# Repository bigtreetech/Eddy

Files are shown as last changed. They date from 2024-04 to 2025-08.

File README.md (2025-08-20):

# Installation Guide For EDDY USB And Eddy Coil

> [!IMPORTANT]
> It is no longer necessary to use the BIGTREETECH fork when using the Eddy. You can now run mainline klipper. The guide that follows assumes that you are running mainline klipper. If you are migrating from the BIGTREETECH fork back to mainline then we suggest erasing all of the configuration and calibration data in your config file (including that within the auto save section) and performing the calibration again while using our latest configuration files.

# Index

- [BTT Eddy Dimensions and Probe Location](#btt-eddy-dimensions-and-probe-location)
- [Compiling Firmware](#compiling-firmware)
- [Printer Configuration](#printer-configuration)
- - [Selecting the right config file for your needs](#selecting-the-right-config-file-for-your-needs)
- - [Z Endstop](#z-endstop)
- [Drive Current Calibration](#2-drive-current-calibration)
- [Mapping Eddy Readings To Nozzle Heights](#3-mapping-eddy-readings-to-nozzle-heights)
- [Bed Mesh Calibration](#4-bed-mesh-calibration)
- [Temperature Compensation Calibration](#5-temperature-compensation-calibration-eddy-usb-only)
- [Extra Info](#extra-info)
- - [Bed Mesh Calibration Parameters](#bed-mesh-calibrate-parameters)
- - [Bed Mesh Scan Height](#bed-mesh-scan-height)
- - [Bed Mesh Rapid Scanning](#rapid-continuous-scanning)
- [FAQ - Frequently Asked Questions](#faq---frequently-asked-questions)
- - [Sometimes I get Error during homing probe: Eddy current sensor error](#sometimes-i-get-error-during-homing-probe-eddy-current-sensor-error)
- - [Sometimes I get a "Probe Triggered Before Movement" Error](#sometimes-i-get-a-probe-triggered-before-movement-error)
- - [Eddy is performing Z Hops when running Bed Mesh](#eddy-is-performing-z-hops-when-running-bed-mesh)
- - [Which Eddy version should I use?](#which-eddy-version-should-i-use)
- - [Error: gcode command < ANY GCODE COMMAND > already registered](#error-gcode-command--any-gcode-command--already-registered)
- - [My z-offset doesnt seem to save and resets, is there a work around or fix?](#my-z-offset-doesnt-seem-to-save-and-resets-is-there-a-work-around-or-fix)
- - [My Eddy Macros Conflict With My KNOMI Macros](#my-eddy-macros-conflict-with-my-knomi-macros)
- - [KAMP And Eddy](#kamp-and-eddy)

## Video Tutorial

For a video tutorial covering many of the points below, please watch the [video located here](https://drive.google.com/file/d/1uXiymZxoWhvRIwTwojOh0fGKmjitoytf/view?usp=sharing)

## BTT Eddy Dimensions and Probe Location

The Eddy has been designed to mount onto a standard Voron X carriage where the Omron inductive probe would usually mount. Additional mounts are provided for common printers [within the 3D folder of this repo.](https://github.com/bigtreetech/Eddy/tree/master/3D/EDDY_PRINT_PARTS) For detailed wiring and mounting instructions for both the Eddy and Eddy Coil, please refer to the PDF manual.

In all cases, mount the Eddy between 2mm and 3mm from the surface of the bed when the nozzle is just touching the bed. Mounting it too close could result in probe errors from the oscillator circuit signal saturating and mounting it too far could result in the oscillator circuit signal collapsing. Use thin shims (such as business cards) to measure this distance approximately.

> [!IMPORTANT]
> When mounting the Eddy, always ensure that the rear (where the electronic components are located) is situated further away from the hotend than the front.

> [!TIP]
> When installing the Eddy (USB version), try to avoid running the cable alongside other cables that are very electrically noisy such as stepper motor cables. If you must run it alongside such cables then do your best to separate the two. If there is slack remaining in the cable, do not wind it in a coil, rather wind it in a figure of 8.

> [!IMPORTANT]
> Some people confuse the current calibration height of 20mm with the mounting height of 2-3mm. The 20mm height is only used when calibrating the coil current later in this guide.

The dimensions below will help you to understand where the center of the coil is when measuring the X and Y offsets from point 15.

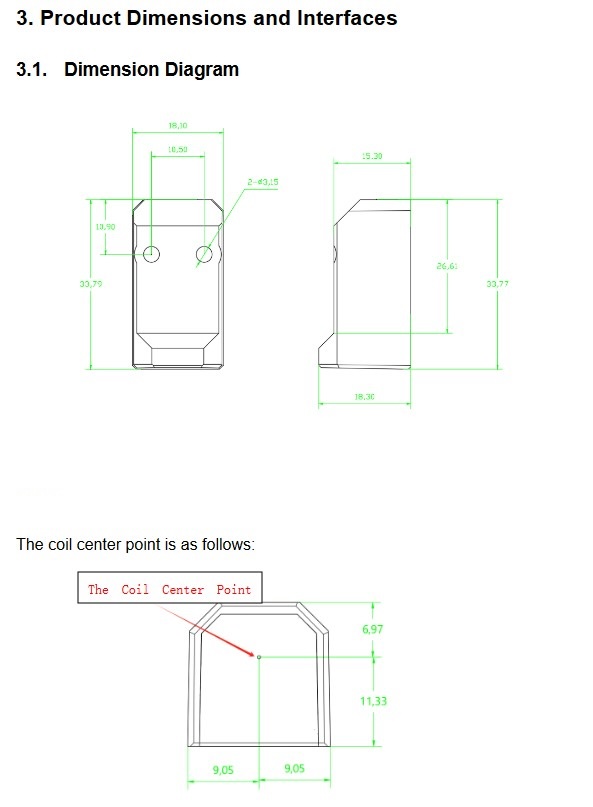
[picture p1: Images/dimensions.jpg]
Dimensions


## Compiling Firmware

> [!IMPORTANT]
> Eddy and Eddy Coil are ONLY compatible with klipper installations that are using a virtual environment based on python 3. Even if you have python 3 installed on your system this does not mean that your klippy virtual environment has been created using python 3. If you receive an error that says something like: `Internal error during connect: split() takes no keyword arguments` then you have a klippy host that is based on a python 2 virtual environment and you need to get it upgraded. The easiest way to do this is to use [KIAUH](https://github.com/dw-0/kiauh) which will allow you to reinstall the klippy host without overwriting your configs while selecting the python 3 option.

> [!IMPORTANT]
> The firmware compilation instructions below only apply to the Eddy USB. If you are using an Eddy Coil then you will have it connected to the I2C port on a toolboard. You will need to compile firmware for that toolboard using the master klipper branch and then install it onto that toolboard. When configuring the Eddy within Klipper you will just need to specify that it communicates using the I2C port on that toolboard which will depend on the pins for that board.
>
> If you are coming from the old BIGTREETECH branch of klipper then we recommend using KIAUH to move back to the mainline branch. We also recommend updating the firmware on all of your klipper devices so that it too is running on a binary compiled from mainline.

1. Ensure that you are using mainline klipper by typing the following commands via SSH:

```
cd ~/klipper
git checkout master
```

> 2. Next, type

```
cd ~/klipper
make menuconfig
```

3. Use these settings to compile the firmware.

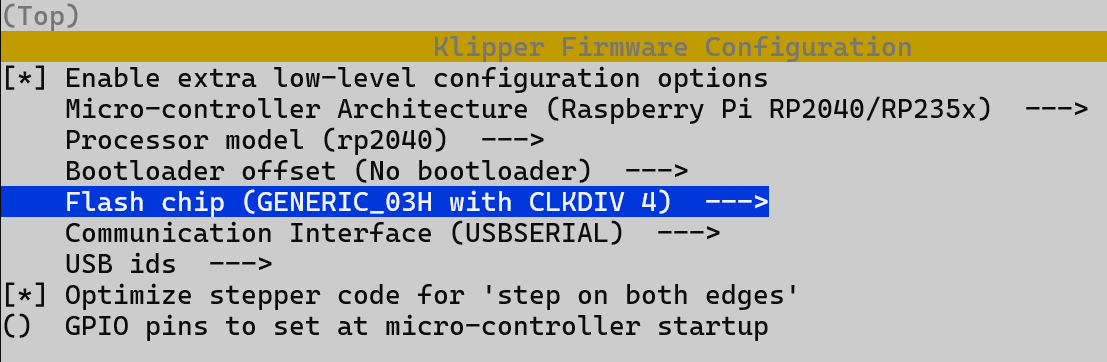
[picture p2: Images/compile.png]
Firmware Image
   

> [!WARNING]
> If you do not change the Flash chip configuration to the CLKDIV 4 one pictured, your probe will appear to work normally at first, however it will only intermittently start up when powered on. 

5. Once set, hit 'Q' and when asked, select yes to save.
6. Type `make` to compile.
7. Disconnect power to Eddy
8. Push and hold boot button on Eddy (Its next to where the cable plugs in) and at the same time, plug in the cable to your BIGTREETECH Pi.

> [!IMPORTANT]
> Don't disassemble your Eddy. The button is fully accessible without disassembly. The image is shown in an exploded view to make the button easier to see.

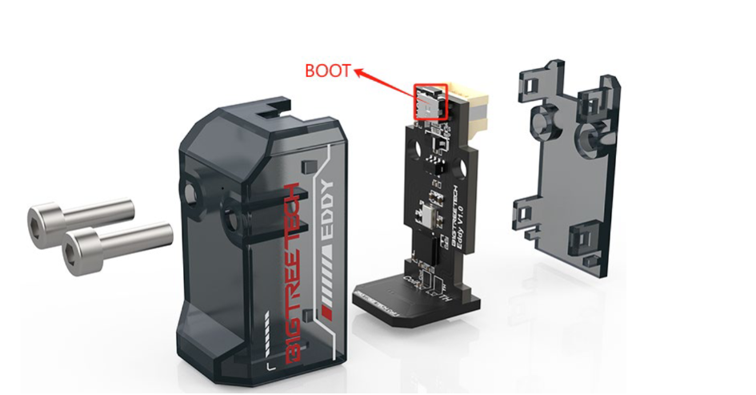
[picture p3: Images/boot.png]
Boot Image


8. SSH into host device
9. Type `lsusb` into the command line. You should see eddy.

LSUSB Image

10. Type `cd ~/klipper` into command line
11. Type `make flash FLASH_DEVICE=2e8a:0003`
    Remember to change 2e8a:0003 to your device ID you found in step 9
12. Type `ls /dev/serial/by-id/*` into the command line. The found device will be what you enter into your klipper config under [mcu eddy] for the Serial variable.

13. Type into command line `sudo reboot`

## Printer Configuration

> [!IMPORTANT]
> Read these steps well. Following them closely will help to ensure that your installation works without any hassles.

### Select the right config file for your needs

14. Now that you have the right firmware loaded onto your device, it is time to complete the Klipper configuration. BIGTREETECH provides three different sample configuration files to get you going. You will need to decide which one suits your needs the best. Choose the file that works best for you based on the criteria below. Read the comments in the selected configuration file carefully as they will help you to understand how to modify certain parameters to your installation.

- You wish to use the Eddy as a probe but will use another device as the z-endstop - [Use this config with no homing](sample-bigtreetech-eddy.cfg)
- You wish to use the Eddy as a probe AND as the z-endstop - [Use this config which includes homing](sample-bigtreetech-eddy-homing.cfg)
- You wish to use the Eddy as a probe AND as the z-endstop and would like to use the beta z-offset functionality - [Use this config which includes homing and z-offset](sample-bigtreetech-eddy-zoffbeta.cfg)

Whichever config you select, copy the entire contents into your printer.cfg file.

### Z Endstop

As mentioned in the paragraph above, you can use the Eddy as the z endstop or you can use another device as an endstop. If you decide to use another device as an endstop then set up your homing and endstop according to that device.

15. If you want to enable Z-Homing/Endstop for the eddy do the following things:

a. Under your [stepper_z] in printer.cfg change `endstop_pin: PA5` to `endstop_pin: probe:z_virtual_endstop` and comment out or remove `position_endstop: 0`. Note that your current endstop may not be PA5 so just look for the line that matches your current endstop and change it.

b. Ensure that you have selected the correct sample configuration file and that the entire contents of that file have been copied into your `printer.cfg file`. Take note that if you are using a KNOMI then there may be some macros that conflict with the macros in the KNOMI.cfg file. To resolve the conflicts, comment out the macros in the KNOMI.cfg file and uncomment the lines from the Eddy macros that deal with KNOMI functionality.

c. Edit the parts of the config file that are unique to your setup. These may be things like those in the list below. Follow the comments in the config file to help you to edit the values so that they work best with your setup.

- MCU serial
- X offset and Y offset
- Mesh_min and mesh_max
- Home_xy_position

> [!IMPORTANT]
> The sample configuration requires you to adjust the **x_offset** and **y_offset** to match your probe position relative to your nozzle. You can do that by following these steps found [HERE](https://www.klipper3d.org/Probe_Calibrate.html) and also by using the images at the top of this guide which show the center location of the Eddy coil. The settings for the standard Voron X carriage mount are included in all sample configuration files.

## 2. Drive Current Calibration

With the firmware and configuration done, you are now ready to begin the probe calibration.

16. Place Eddy Approx. 20mm above the bed. If you plan to use the Eddy as an endstop then you will not yet be able to home with it and you will need to manually move the gantry or bed such that the Eddy is 20mm above the bed.
17. From Mainsail or Fluidd run the command `LDC_CALIBRATE_DRIVE_CURRENT CHIP=btt_eddy`
18. Type `SAVE_CONFIG` to save the drive current to your config

## 3. Mapping Eddy Readings To Nozzle Heights

Now that the drive current has been calibrated, the Eddy will be able to obtain readings from the print bed. Klipper needs to know how those readings correspond to the height of the nozzle. The following calibration procedure positions the nozzle on the bed so that the z height is = 0. It then takes readings from the Eddy as it gradually increases the nozzle height so that it can map those readings to known heights. Follow the steps below to perform this essential calibration.

> [!TIP]
> If you ever find that the nozzle is sitting either too high or too low when it is supposed to be at z=0 then performing this quick calibration again will likely solve your issue. There is no need to set a z-offset. Movement of the probe relative to the nozzle through maintenance may result in the need for this calibration.

> [!TIP]
> Choose your own adventure!
> If you want to run the mapping the manual way then follow steps 22 thru 26
> If you want the easy way then simply follow steps 19 thru 21

19. Send the command `PROBE_EDDY_CURRENT_CALIBRATE_AUTO CHIP=btt_eddy`
20. Follow the prompts on the klipper UI to lower the nozzle until it sandwiches a piece of paper between it and the bed but be careful not to dig into the bed. The paper should still be able to move with some force applied.
21. Click accept and watch as the Eddy performs the mapping. Be sure to send `SAVE_CONFIG` when it is done. Skip ahead to [Bed Mesh Calibration](#4-bed-mesh-calibrationbed-mesh-calibration).

> [!TIP]
> Only perform the steps below if you did not perform steps 19 thru 21.

22. Home X and Y axes with command `G28 X Y`
23. Make sure you dont have a bed heightmap loaded. Send `BED_MESH_CLEAR` from the console to clear the heightmap.
24. Move Nozzle to Centre of the bed with `G0 X125 Y125 F6000` . The given command assumes a 250x250 printer but you will need to adjust it for your bed size. Take your bed size and divide it by 2 on X and Y and then use those values for the X and Y values in the command.
25. Start the mapping by typing `PROBE_EDDY_CURRENT_CALIBRATE CHIP=btt_eddy`. You will see an adjustment box that will allow you to lower the nozzle. Lower the nozzle until it sandwiches a piece of paper between it and the bed but be careful not to dig into the bed. The paper should still be able to move with some force applied.

26. Once completed use `SAVE_CONFIG`

## 4. Bed Mesh Calibration

> [!IMPORTANT]
> Before you do this, it's a good idea to perform a Quad Gantry Leveling (Voron etc)

27. Home All Axes
28. Use command `BED_MESH_CALIBRATE METHOD=rapid_scan`
29. Once completed use `SAVE_CONFIG`

## 5. Temperature Compensation Calibration (Eddy USB ONLY)

> [!TIP]
> The following steps (30-38) are for Eddy USB Only. Eddy Coil doesnt have temperature compensation so these steps should be disregarded.

30. Home All Axes and move Z 5 mm above the bed by typing `G0 Z5` or using the movement UI.
31. Set idle timeout by typing `SET_IDLE_TIMEOUT TIMEOUT=36000`
32. Run `TEMPERATURE_PROBE_CALIBRATE PROBE=btt_eddy TARGET=56 STEP=4`
33. This will cause the UI to display the z axis adjustment box. Use [the paper method](https://www.klipper3d.org/Bed_Level.html#the-paper-test) mentioned here to pinch a sheet of paper between the nozzle and the bed and then accept the value.
34. Turn on your heat bed to the maximum value and your nozzle to 220C.
35. If you are in a room with an air-conditioner or an open window, it would be good to turn it off and/or close the window. We want the temperature of the Eddy to rise and breezes will stop that.
36. As the Eddy temp rises you will automatically be asked to perform the paper pinch method at each 4C interval. Be careful not to burn yourself on the bed as the bed can get quite hot.
37. Repeat the paper test method until the calibration completes. If you find that the temperature of the Eddy is no longer increasing then you can end the calibration early using the relevant command below.

> [!NOTE]
> By default the calibration procedure will request a manual probe every 4C between samples until the TARGET is reached.
>
> The following additional gcode commands are available during drift calibration.
>
> `TEMPERATURE_PROBE_NEXT` may be used to force a new sample before the step delta has been reached.
>
> `TEMPERATURE_PROBE_COMPLETE` may be used to complete calibration before the TARGET has been reached.
>
> `ABORT` may be used to end calibration and discard results.

> [!TIP]
> The Eddy thermal calibration process not only accounts for Eddy probe drift but it also accounts for thermal expansion of the mechanical components within your machine. This expansion can be very significant and it can result in poor first layers when using other probes. It is important to keep in mind that if you perform the thermal calibration with the nozzle and the heated bed turned on then there will be thermal expansion from both the hotend and the heated bed. Therefore, if you later try to perform a paper test and only have either the nozzle or the heated bed turned on you may find that there is about a 0.05 gap (not enough to cause a first layer issue but enough to feel less of a pinch on the paper). If this all sounds a bit confusing then don't worry. All you need to know is that you should perform the calibration with the bed and the nozzle both hot and then subsequently print with the bed and the nozzle both hot and you will get fantastic first layers.

38. Youre all done and your Eddy will now give you a beautiful first layer across a wide temperature range! :)

# Extra Info

## Z-Offset

> [!TIP]
> This section only applies to those who are using the Eddy for homing.

The Eddy should not need the use of a z-offset since it is calibrated to understand where `z=0` is. Nevertheless, if you would like to use a z-offset then you should use the [sample config file that includes z-offset functionality.](sample-bigtreetech-eddy-zoffbeta.cfg)

To determine the correct Z-offset, follow the steps below.

- Home your printer.
- Place a piece of paper beneath the nozzle.
- Use mainsail or fluidd to set the z height to `z=0`. DO NOT babystep to get the nozzle to `z=0`! Set it as the z-axis height.
- After setting the z-axis height to `z=0` check if the pinch on your paper is just right. If not, then use babystepping to go up or down.
- After babystepping to the correct height, save the adjustment using the button on the mainsail or fluidd UI.

## Bed Mesh Calibrate Parameters

The Eddy allows you to perform a very rapid bed mesh scan before each print to ensure that you get the best first layer possible. To do this, we recommend replacing the standard BED_MESH_CALIBRATE macro with our modified version from the sample configuration file and then including a BED_MESH_CALIBRATE call in your print start macro.

To find out more about the parameters used in the bed mesh scan you can read the Klipper documentation here: [Bed Mesh Calibration](https://www.klipper3d.org/G-Codes.html#bed_mesh_calibrate)

## Bed Mesh Scan Height

The scan height is set by the `horizontal_move_z` option in `[bed_mesh]`. In
addition it can be supplied with the `BED_MESH_CALIBRATE` gcode command via the
`HORIZONTAL_MOVE_Z` parameter.

The scan height must be sufficiently low to avoid scanning errors. Typically
a height of 2mm (ie: `HORIZONTAL_MOVE_Z=2`) should work well, presuming that the
probe is mounted correctly.

It should be noted that if the probe is more than 4mm above the surface then the
results will be invalid. Thus, scanning is not possible on beds with severe
surface deviation or beds with extreme tilt that hasn't been corrected.

## Rapid (Continuous) Scanning

When performing a rapid bed mesh scan there is little time to accumulate many samples per point so that they can be averaged and have noise removed. Therefore a rapid scan may not be as accurate as a standard bed mesh scan but in most cases it will still produce a fine first layer.

Rapid scans can be improved by allowing the travel planner to slightly overshoot the scanned bed mesh and smooth the moves. You can configure this overshoot in the bed_mesh configuration section using the `scan_overshoot: ` parameter. Note that you will need to ensure that the axis can travel to the mesh boundary plus this overshoot value on your printer so be careful not to specify a value that is too high. Usually 8mm is plenty.

# FAQ - Frequently Asked Questions

## Sometimes I get `Error during homing probe: Eddy current sensor error`

- This generally indicates that the oscillator within the Eddy sensor is not at a valid value before the probe/homing attempt starts. We recommend trying the following steps:

1. Double check your probe height. It may be that it is too close to the bed or too high. Remember that we recommend that it is at 2mm-3mm above the bed when the nozzle is just touching the bed. Around 2.5mm is optimal in most cases but if you are finding that your probe is having errors at high temperatures then try to drop it just below 2mm. However, if your probe is having errors during QGL attempts then you may need to raise it slightly.
2. After you have adjusted the probe height, remove all of the calibration settings from your config file and recalibrate the eddy.
3. If you still receive this error then increase the `reg_drive_current` value to 16 from 15 if it is currently set to 15.

## Sometimes I get a "Probe Triggered Before Movement" Error

- This will happen when you try to execute two successive `PROBE` commands. Always raise the gantry by a few mm between `PROBE` commands to avoid this.

## Eddy is performing Z Hops or pausing when running Bed Mesh

- Make sure you are using the correct macro call.
  `BED_MESH_CALIBRATE METHOD=rapid_scan`
- Remove or alter KAMP - Adaptive Bed Mesh and any custom BED_MESH_CALIBRATE macros. Use klipper adaptive mesh instead or alternatively do not include KAMP/Adaptive_Meshing.cfg in your KAMP_Settings.cfg
  [Information on Adaptive Mesh Here](https://www.klipper3d.org/Bed_Mesh.html#adaptive-meshes)

## Which Eddy version should I use?

- It depends on your needs. Eddy USB and Eddy Coil are nearly identical, however Eddy Coil is more for toolhead boards and connects via I2C connectors.
- Eddy Coil does not have temperature compensation and so it may be less reliable for homing if you are using it within a sealed chamber..

## Error: gcode command < ANY GCODE COMMAND > already registered

- This will happen when you have conflicting gcode macros. Check all of your gcode macros for ones that share the same name and arbitrate the conflicts. Generally, you should select the functionality from the Eddy macros if there is a conflict and you are not sure what to do.

## My z-offset doesnt seem to save and resets, is there a work around or fix?

- Coming from a standard probe, this may seem like a bug. However if you have calibrated the Eddy correctly and are using the special homing macros, then there will be no need for a z-offset. Explaining why is a bit long winded but essentially when it comes to an Eddy, the z-offset parameter does not adjust the height at which the nozzle prints, it just adjusts the height at which homing or probing triggers. If you have a mind that enjoys understanding things at a deeper level then here is a writeup to give you something to chew on: [Z-Offsets with Eddy Current Probes](https://gist.github.com/bigtreetech/484380b26be613b9139bc537510393df)
- While we strongly recommend simply performing the Eddy probe calibration in order to get a nozzle height that is just right, you can still simulate a standard z-offset by using the [Z-offset beta sample configuration file](sample-bigtreetech-eddy-zoffbeta.cfg). Simply uncomment any macro that is related to the beta z-offset functionality and you will be able to use the standard mainsail buttons to raise/lower then nozzle and save that height as a z-offset.

## My Eddy Macros Conflict With My KNOMI Macros

- The Eddy and the KNOMI share similar Macros. All of the needed functionality for the KNOMI has been built into the Eddy macros. Please comment out the KNOMI macros which conflict and use the Eddy macros.
- Note that you may need to uncomment some lines in the Eddy macros that are specifically included for people who run the KNOMI. Check the macros to see which lines have been commented and then uncomment them if they are needed for KNOMI.

## KAMP And Eddy

> [!WARNING]  
> [KAMP aka Klipper-Adaptive-Meshing-Purging](https://github.com/kyleisah/Klipper-Adaptive-Meshing-Purging) should be removed from your klipper prior to using Eddy. Please comment out the include line. ie `#[include ./KAMP/adaptive_meshing.cfg]` from your KAMP_SETTINGS.cfg
>
> Instead KAMP has been integrated into klipper as of January 2024 and you should use the ADAPTIVE=1 option in your BED_MESH_CALIBRATION calls. You can find more [Information on Adaptive Mesh Here](https://www.klipper3d.org/Bed_Mesh.html#adaptive-meshes)

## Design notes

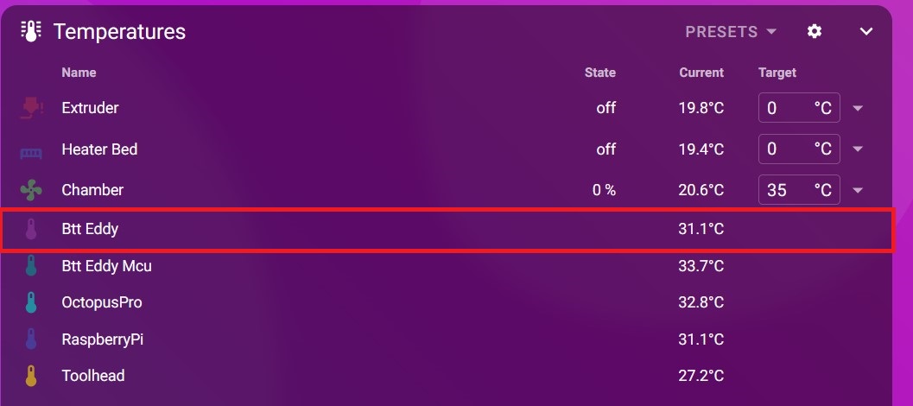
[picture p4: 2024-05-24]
Images/eddy-temp.jpg

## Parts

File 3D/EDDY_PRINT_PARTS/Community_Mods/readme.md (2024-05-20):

* The `Community_Mods` file is for 3D printing community users to share and contribute models. We are very grateful for their sharing and contribution. However, these files have not been verified by BIGTREETECH and may have compatibility issues. If you encounter compatibility issues as a result, please let us know by initiating an [issues](https://github.com/bigtreetech/Eddy/issues)

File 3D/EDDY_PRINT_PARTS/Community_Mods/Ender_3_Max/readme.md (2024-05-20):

Adjustable mount for BTT Eddy probe v1 ( USB probe version ) to fit Creality Ender 3 Max carriage plate

Designed by @DaveTheBuskerUK - 20240510

There are 2 parts to the actual mount -

The slide has holes in it for the supplied M3 bolts that come with the Eddy probe, I use the shorter 2, the holes are sized to self tap when you screw in the m3 bolts, if they pull out you could use the longer bolts with nylock nuts on the back of the slide. At the top of the slide is a pair of larger holes for a cable tie to retain the probe cable. Then the long slotted hole is for 2 M3x10mm bolts which go through the slide, through the spacer and fit into the threaded holes in the E3 Max carriage plate, these allow for vertical adjustment of the probe.

The spacer fits between the slide and the carriage plate, this is needed to offset the slide so it doesn't collide with the bolts on the belt adjuster. I created a recess in the spacer so it also helps the slide not drift sideways and should keep it at 90 degrees to the bed.

I also created the block, I used this to quickly configure the height adjustment for the Eddy probe, it's meant to be around 1 to 2mm higher than the tip of the nozzle, so with the nozzle just touching the build surface you can place the shorter pad on the block under the Eddy probe and adjust the slide until the Eddy probe is just touching the block, then with the two bolts tightened you can manually raise z up until the taller pad on the block can sit under the Eddy probe, that puts the probe at about 20mm above the build surface for it's intitial calibration. The blcok can be found in the Eddy_Calibration_Block folder if you are reading this on GitHub.

I printed all 3 parts in PLA, 0.20mm layer height, 23% infill and added 2 m3X10mm button head bolts for mounting.

This puts the probe offsets at about 50 x and 5 y but you will need to measure your own install to check.

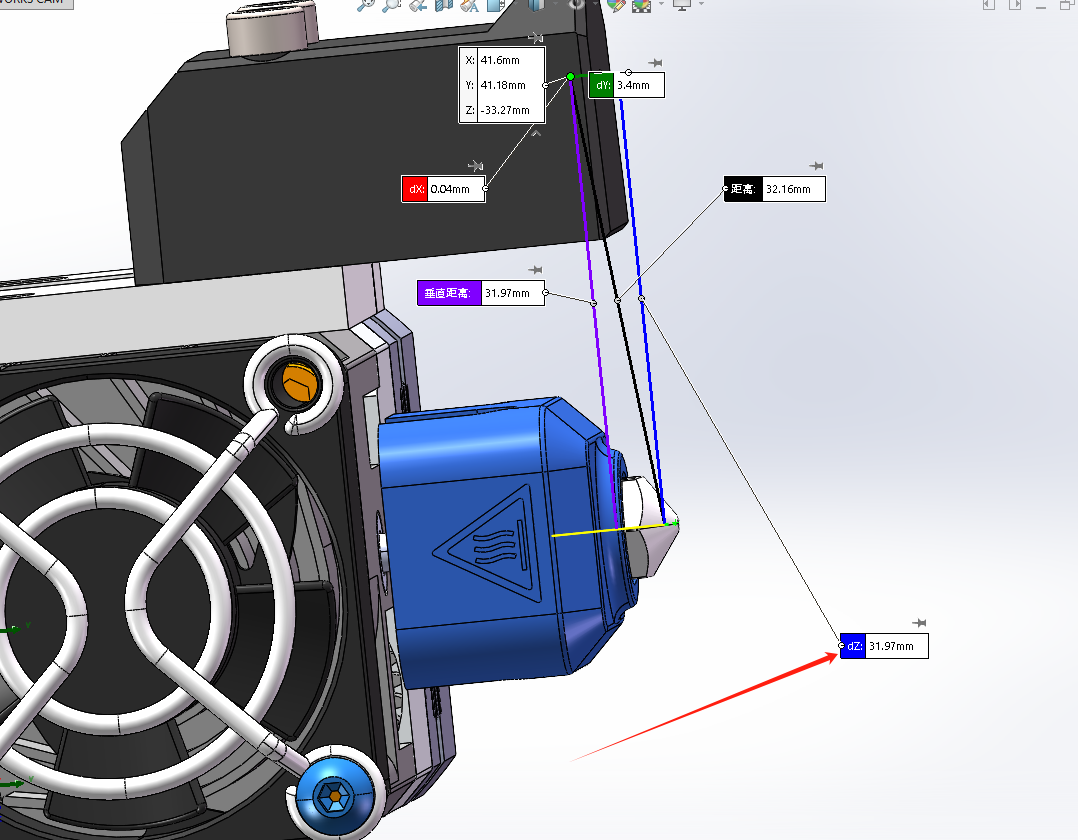
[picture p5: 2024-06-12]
3D/EDDY_PRINT_PARTS/EDDY mount for the H2 V2S .png

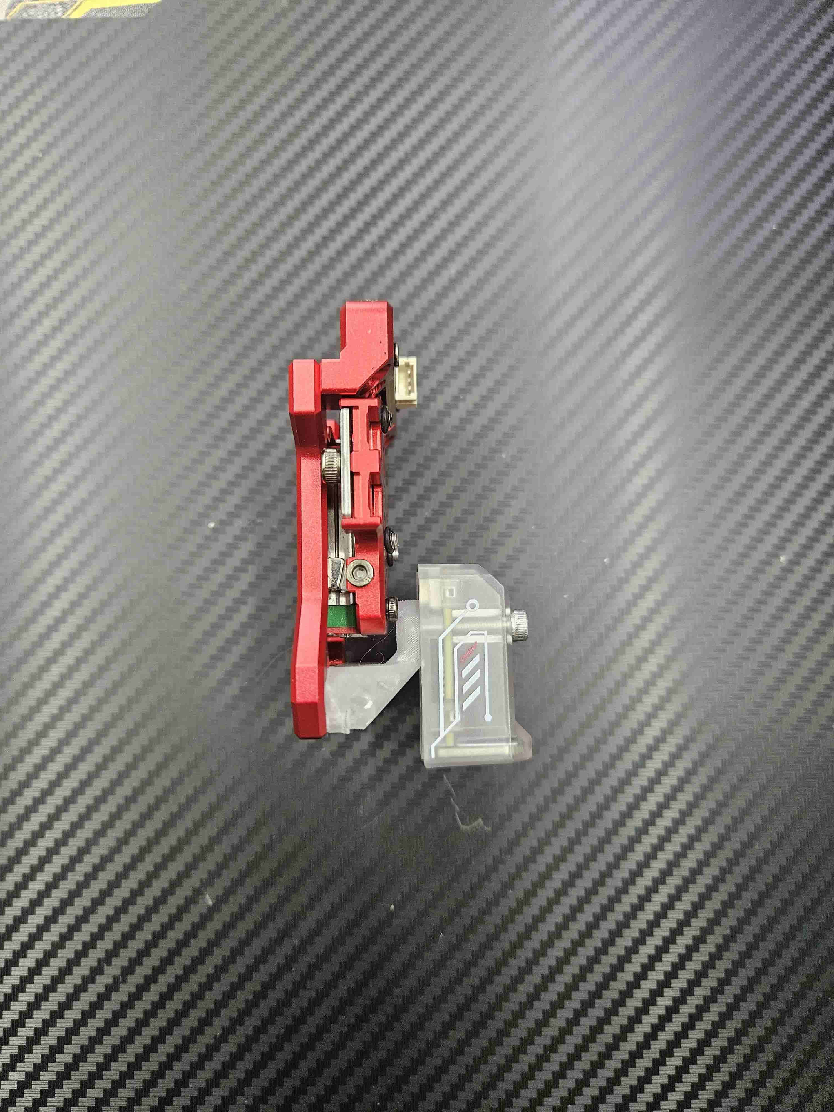
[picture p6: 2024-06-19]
3D/EDDY_PRINT_PARTS/Eddy_TapV2/Eddy-Tap V2 (2).jpg

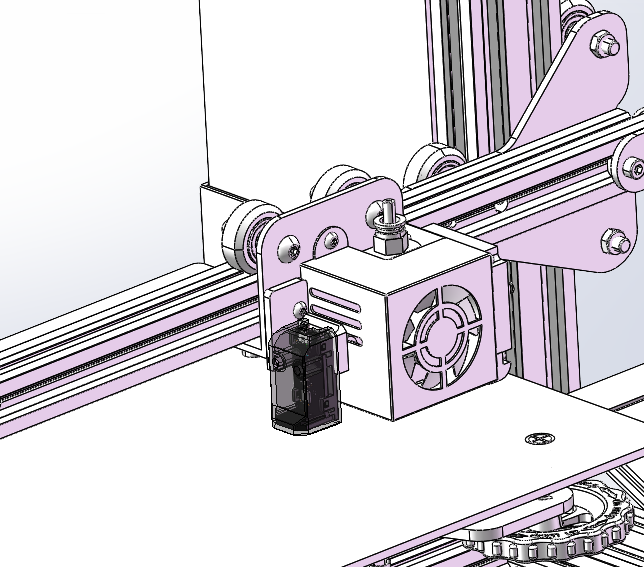
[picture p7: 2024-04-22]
3D/EDDY_PRINT_PARTS/Ender 3/Eddy-Ender3mount固定架.png

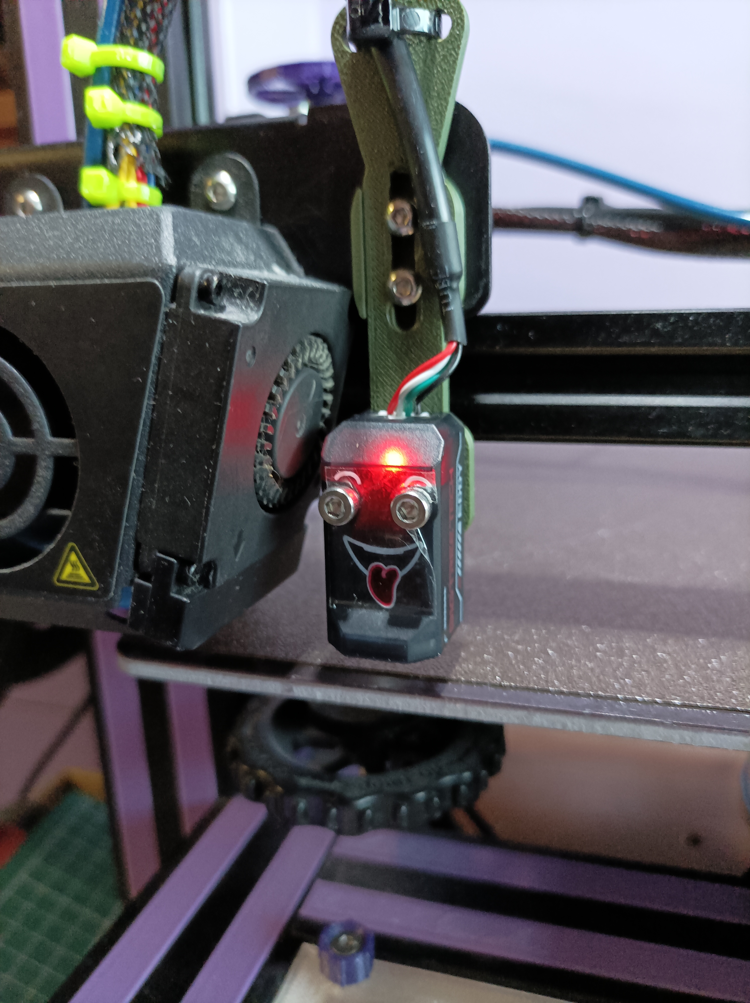
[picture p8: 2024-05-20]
3D/EDDY_PRINT_PARTS/Community_Mods/Ender_3_Max/Eddy-Mount-IMG_20240510_200312.jpg

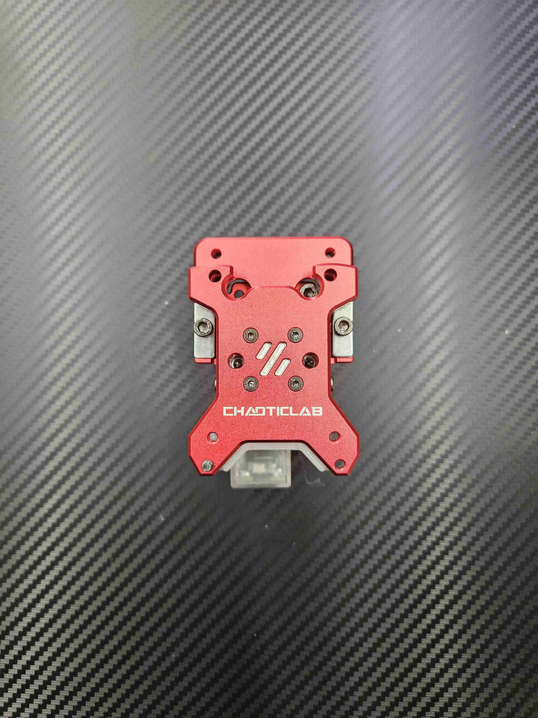
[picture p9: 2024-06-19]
3D/EDDY_PRINT_PARTS/Eddy_TapV2/Eddy-Tap V2 (1).jpg

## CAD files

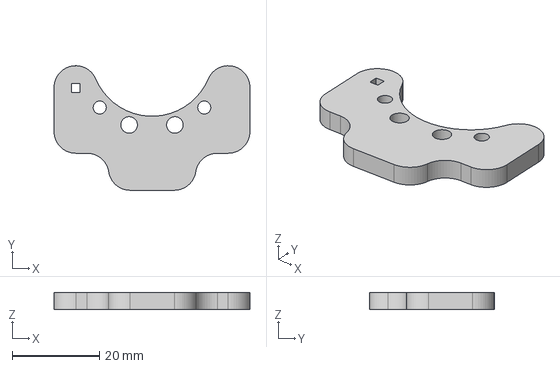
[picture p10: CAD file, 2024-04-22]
3D/EDDY_PRINT_PARTS/B1/B1_Eddy_mount固定架V2.step
45.0 x 28.6 x 4.00 mm

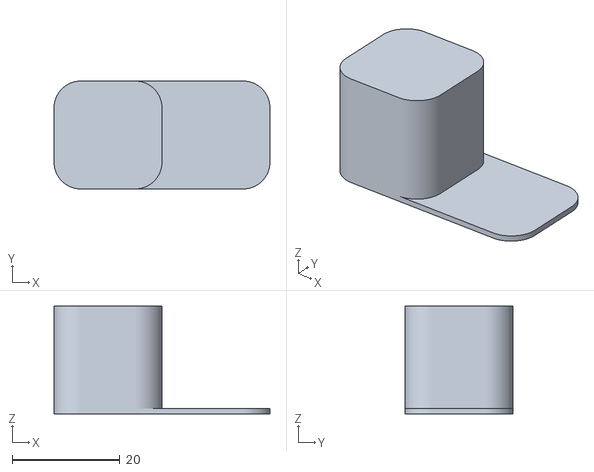
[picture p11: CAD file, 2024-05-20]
3D/EDDY_PRINT_PARTS/Community_Mods/Eddy_Calibration_Block/E3Max-BIQU_Eddy_Probe_Mount-Block-V0-1.stl
40.0 x 20.0 x 20.0

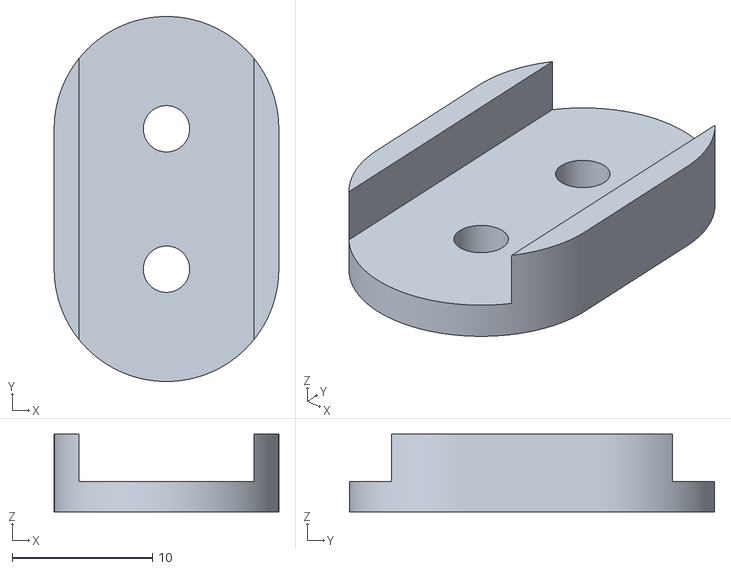
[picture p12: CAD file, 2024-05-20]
3D/EDDY_PRINT_PARTS/Community_Mods/Ender_3_Max/E3Max-BIQU_Eddy_Probe_Mount-Spacer-V0-1.stl
16.0 x 26.0 x 5.54

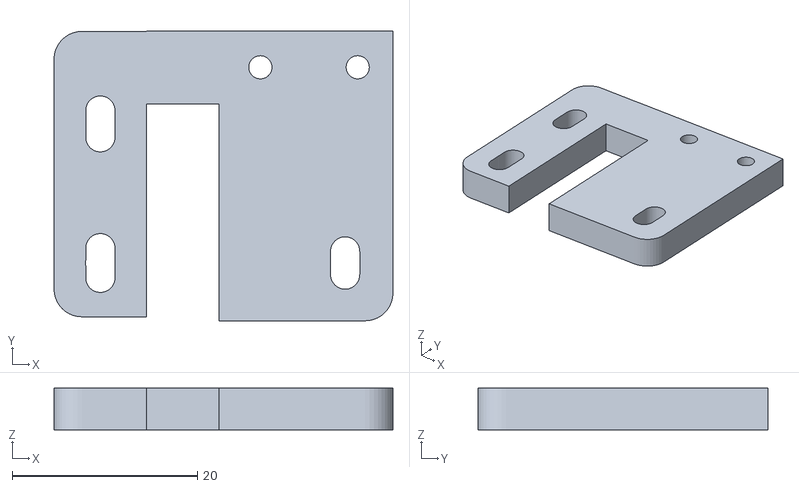
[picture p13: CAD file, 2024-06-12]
3D/EDDY_PRINT_PARTS/EDDY mount for the H2 V2S 31.93mm 20240611 .STL
36.6 x 31.2 x 4.50

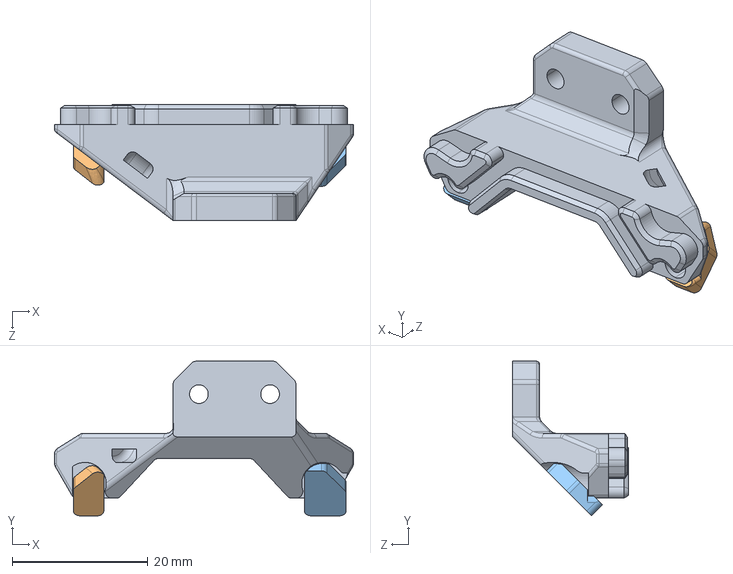
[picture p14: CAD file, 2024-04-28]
3D/EDDY_PRINT_PARTS/Eddy_TapV2/TAP V2-Eddy-0424.STEP
44.1 x 22.8 x 17.1 mm

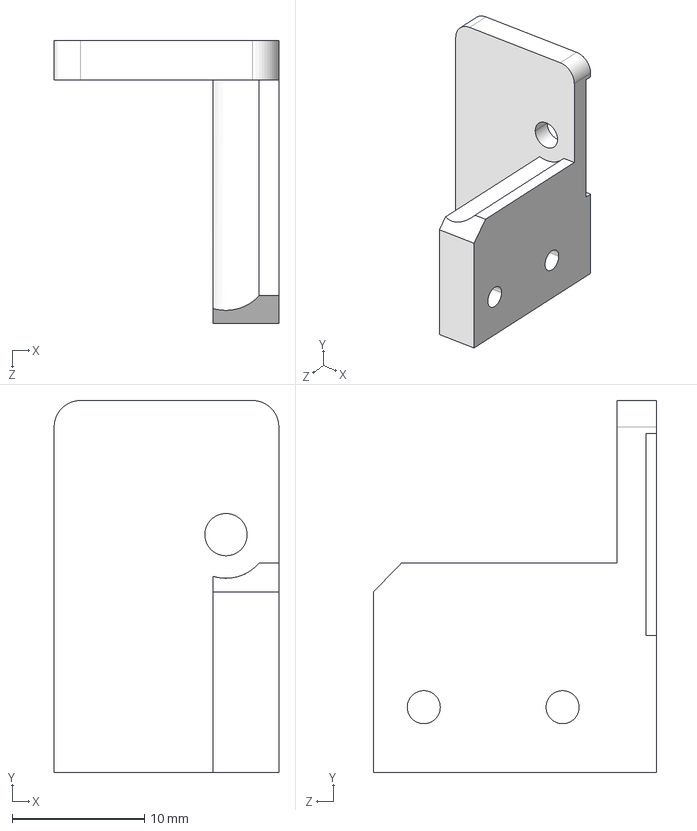
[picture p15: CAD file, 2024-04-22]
3D/EDDY_PRINT_PARTS/Ender 3/Eddy-Ender3_mount固定架.STEP
17.0 x 28.1 x 21.4 mm

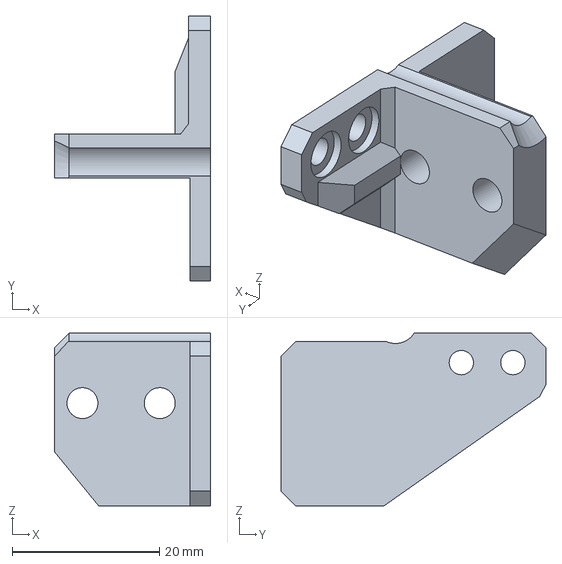
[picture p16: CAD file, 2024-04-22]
3D/EDDY_PRINT_PARTS/EVA3/Eddy_Front_facing_mount.step
21.2 x 36.0 x 23.5 mm

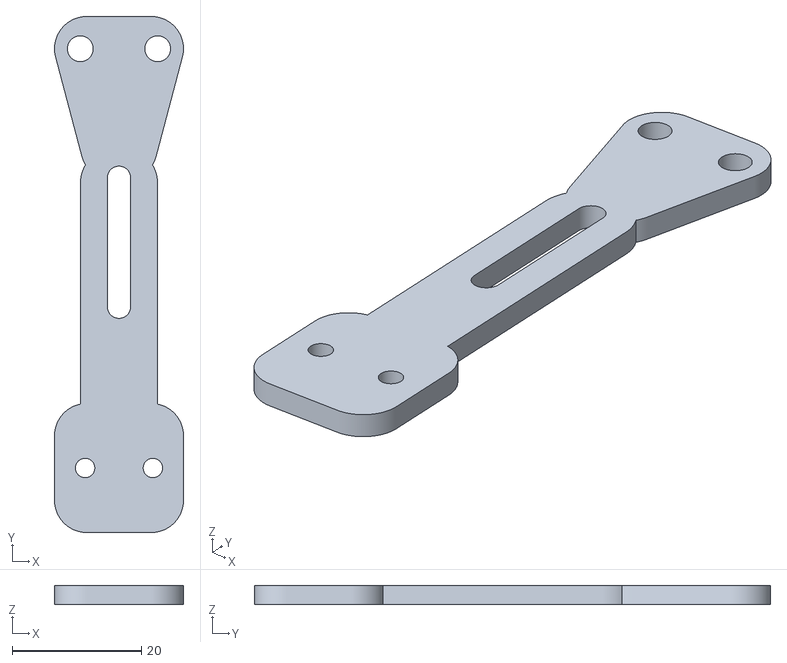
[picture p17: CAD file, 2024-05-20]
3D/EDDY_PRINT_PARTS/Community_Mods/Ender_3_Max/E3Max-BIQU_Eddy_Probe_Mount-Slide-V0-1.stl
20.0 x 80.0 x 3.00

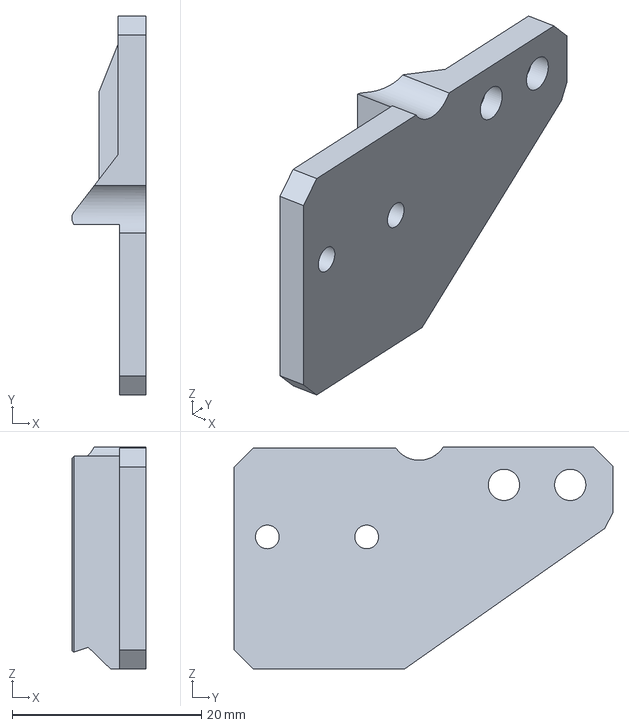
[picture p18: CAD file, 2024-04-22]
3D/EDDY_PRINT_PARTS/EVA3/Eddy_side_facing_mount.step
7.87 x 40.0 x 23.5 mm

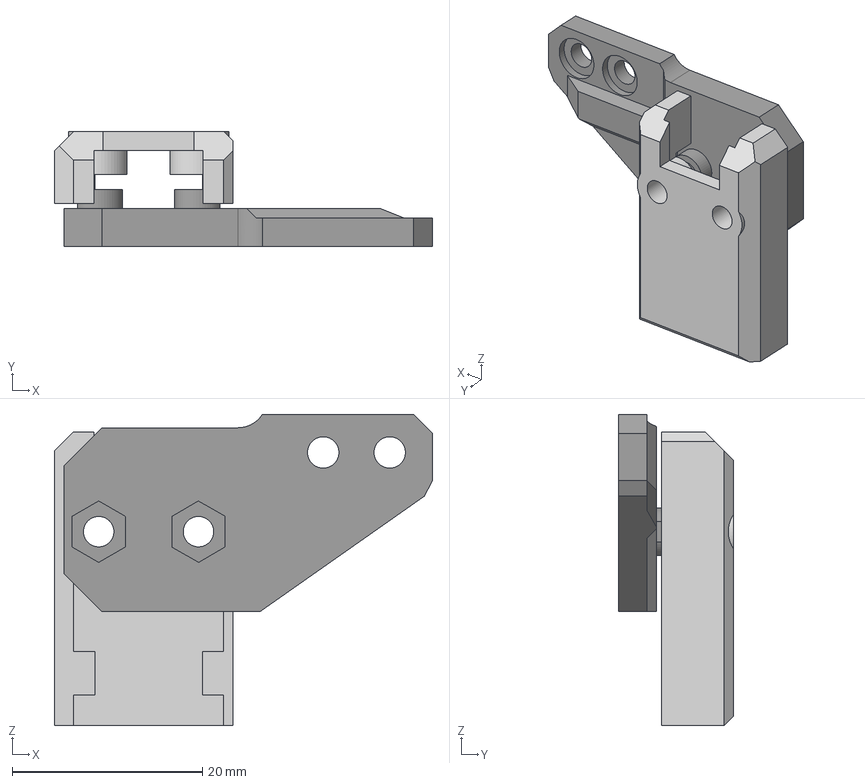
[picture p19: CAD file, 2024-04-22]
3D/EDDY_PRINT_PARTS/EVA3/Eddy_Naked_mount.step
39.8 x 12.1 x 32.7 mm
Eddy Naked mount_1
Case Front

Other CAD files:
3D/EDDY_PRINT_PARTS/Ender 3/Eddy-Ender3mount固定架.STL

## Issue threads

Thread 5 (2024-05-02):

Z Offset Changing

krautech, 2024-05-02:
Unfortunately everytime I have to printer restart (I think) eddy seems to ignore the z offset that's been set using live printing and saving from the console in mainsail. I can see it adding to the printer.cfg that the z_offset is changing when saving it, yet whenever I have to restart my printer, I need to adjust my z_offset by 0.2mm everytime roughly. I started with a z_offset of 1 and now I'm at near 2mm!! It continues to happen again and again. Nothing in my setup changes other than a restart.

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

[klippy(6).log](https://github.com/bigtreetech/Eddy/files/15184658/klippy.6.log)

krautech, 2024-05-02:
I redid it fresh, removed all of Eddys config and redid it.

Same problem.

I started with Z_Offset = 1 did the paper test etc all went well, saved it.

Fired up a test print, watched the first layer, too high obviously, so adjusted it -0.125 for a perfect squish, applied and SAVE_CONFIG

z_offset: 1.125 is now in printer.cfg under the do not edit portion.

the SAVE_CONFIG caused a printer restart, so started a new print.
THE Z OFFSET IS THE SAME as before i adjusted it even though it has z_offset set correctly in printer.cfg

So i adjust it. Again its a -0.125 for a perfect squish, SAVE_CONFIG again.

Go look at printer.cfg and its now Z_Offset: 1.250

Something isnt right..

krautech, 2024-05-02:
I manually set z_offset this way
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

Same issue, it doesnt acknowledge the z_offset and i still have to manually adjust -0.125

flyespresso, 2024-05-02:
MidBot's stream of the I think switch wire I think had similar issue. FWIW

allanwrench28, 2024-05-02:
Yep I have the Eddy "Coil" and I have the same issue, I just placed the z offset I needed as a G code line in my start print macro right after G28

krautech, 2024-05-02:
> MidBot's stream of the I think switch wire I think had similar issue. FWIW

I noticed this last night after watching his stream playback as well. Hmm

krautech, 2024-05-02:
> Yep I have the Eddy "Coil" and I have the same issue, I just placed the z offset I needed as a G code line in my start print macro right after G28, and in my end print macro I use G code to clear the offset

Yeah I've done the same until I figure this out. It's annoying but it's not the end of the world.

But I do believe it needs a fix please @bigtreetech

madsi1m, 2024-05-06:
I am also seeing this, i am 1mm off each time. @bigtreetech does need to fix this!
@allanwrench28 what magics did you do to manually set and unset it in the gcode?

sandmmakers, 2024-05-06:
I'm also experiencing similar issues with the USB version installed in a Neptune 3 Max. If I follow all of the "cold directions", the nozzle is too far above the bed to print. I can hand modify the `z_offset` to get a successful print, but I can't figure out the exact relationship between the calibration results and the amount of change I need to apply to the `z-offset`. I've also noticed that when I perform a `PROBE`, the values don't seem correct, since I'm getting values around -4mm. When I perform a cold bed mesh, all of the values are also larger negative values. When I perform the temperature calibration (I've tried at least six+ times), the values from the probe seem more erratic and less consistent. Most of my temperature calibration attempts have had a target value around 64C (Nozzle @260 and bed @100 with an unenclosed 430x430 bedslinger) but I've also tried with a target value closer to 50C.

Creating a cold mesh always completes (I can't speak to the mesh accuracy), but at temp, the mesh will frequently error out with move out of range errors. At one point, I got a `PROBE` result of -99mm, which is obviously incorrect.

With my current bracket, the bottom of the probe is 1mm above the tip of the nozzle.

krautech, 2024-05-07:
I'm over it.

I think I'll be removing eddy and putting my BL touch back on

I just can't get it to be consistent.
Everytime I print I have to manually adjust the z offset. I've calibrated for thermal drift in range 30c to 85c and nothing works.

I might get one good print if I'm lucky and then when I go to do another I'm having to manually change the z offset, which I can't save.

I'm honestly disappointed.

krautech, 2024-05-08:
@madsi1m @flyespresso @sandmmakers @allanwrench28

I can neither confirm or deny at this stage that swapping back to the mainline of klipper instead of btt's klipper will solve or atleast help with some issues.

Eddy has been merged into the main branch of klipper from what I've been told.

madsi1m, 2024-05-08:
Looking at https://github.com/Klipper3d/klipper/pulls?q=eddy I can see that @Arksine did some PRs but doesn't seem to include everything (yet?)
https://github.com/bigtreetech/klipper/commits/eddy/

madsi1m, 2024-05-08:
For me the Eddy USB works fine other than the z offset. my only thing is manual `SET_GCODE_OFFSET Z=<number>` is an absolute number so start with a high number and work your way down

krautech, 2024-05-08:
Yeah I've just found that. Working with someone ATM to figure it out. I'll report back

krautech, 2024-05-08:
> For me the Eddy USB works fine other than the z offset. my only thing is manual `SET_GCODE_OFFSET Z=<number>` is an absolute number so start with a high number and work your way down

What temps are you running everything? I found if I don't heat my enclosure it's fine (minus the z offset issue) but when I heat the enclosure it goes whack and throws the z offset out

madsi1m, 2024-05-08:
no enclosure, but from room temp (cold start) and reprints it seems consistent (bed at 66 degrees)

some random noise no one understands:
```
#*# [probe_eddy_current btt_eddy]
#*# reg_drive_current = 15
#*# calibrate =
#*# 	0.050000:3269931.544,0.100000:3269058.324,0.150000:3268119.785,
#*# 	0.200000:3267239.573,0.250000:3266327.833,0.300000:3265354.825,
#*# 	0.350000:3264522.581,0.400000:3263665.720,0.450000:3262825.103,
#*# 	0.500000:3261878.305,0.550000:3261060.561,0.600000:3260292.457,
#*# 	0.650000:3259547.399,0.700000:3258723.561,0.750000:3257903.601,
#*# 	0.800000:3257106.981,0.850000:3256241.135,0.900000:3255457.651,
#*# 	0.950000:3254623.690,1.000000:3253837.685,1.050000:3253050.210,
#*# 	1.100000:3252328.509,1.150000:3251598.041,1.200000:3250832.687,
#*# 	1.250000:3250120.583,1.300000:3249440.238,1.350000:3248697.232,
#*# 	1.400000:3248002.954,1.450000:3247358.677,1.500000:3246697.628,
#*# 	1.550000:3246020.265,1.600000:3245395.472,1.650000:3244729.586,
#*# 	1.700000:3244134.493,1.750000:3243500.088,1.800000:3242887.414,
#*# 	1.850000:3242285.741,1.900000:3241687.564,1.950000:3241118.487,
#*# 	2.000000:3240598.871,2.050000:3240055.509,2.100000:3239561.220,
#*# 	2.150000:3239038.240,2.200000:3238498.487,2.250000:3238003.609,
#*# 	2.300000:3237544.397,2.350000:3237037.158,2.400000:3236556.467,
#*# 	2.450000:3236077.954,2.500000:3235662.605,2.550000:3235210.751,
#*# 	2.600000:3234781.504,2.650000:3234314.051,2.700000:3233942.738,
#*# 	2.750000:3233548.676,2.800000:3233134.001,2.850000:3232751.718,
#*# 	2.900000:3232337.861,2.950000:3231972.273,3.000000:3231600.079,
#*# 	3.050000:3231226.917,3.100000:3230881.033,3.150000:3230540.783,
#*# 	3.200000:3230210.851,3.250000:3229886.582,3.300000:3229580.396,
#*# 	3.350000:3229236.875,3.400000:3228923.474,3.450000:3228612.058,
#*# 	3.500000:3228326.307,3.550000:3227998.205,3.600000:3227721.665,
#*# 	3.650000:3227423.848,3.700000:3227135.987,3.750000:3226920.543,
#*# 	3.800000:3226633.863,3.850000:3226348.977,3.900000:3226073.794,
#*# 	3.950000:3225818.643,4.000000:3225594.644,4.050000:3225298.757
#*# calibration_temp = 29.848553
#*# drift_calibration =
#*# 	3310127.841833, -554.728091, 2.752797
#*# 	3295137.904060, -467.993916, 2.074839
#*# 	3282545.182362, -393.277901, 1.509666
#*# 	3270547.524380, -274.499385, 0.561740
#*# 	3259506.737881, -155.874581, -0.318383
#*# 	3250420.774441, -73.903284, -0.841705
#*# 	3243146.392618, -31.077439, -1.015140
#*# 	3236971.173436, 13.473592, -1.289882
#*# 	3232475.967612, 28.823786, -1.318070
#*# drift_calibration_min_temp = 27.68500865045914
```

madsi1m, 2024-05-08:
I seem to be off by 1mm after a G28 regardless of bed temp or how heatsoaked the eddy is

krautech, 2024-05-08:
Can you upload your klippy?
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
ifreislich, 2024-05-22:
I spent a very long time on thermal calibration. My process was to creep up on each node from 35C to 70C in 5C steps.  I performed the calibration with my nozzle at my most common print temperature to account for its thermal expansion. Once the Z height paper test is triggered I used an SSH connection to my printer and a series of temperature adjustments from the CLI because both KlipperScreen and Mainsail prevent this once the height dialog starts. I continued to tweak the bed temperature as follows via CLI to ensure that the Eddy was heat soaked at or close to the node temperature before applying the final Z adjustment and accepting the value.
`echo "SET_HEATER_TEMPERATURE HEATER=heater_bed TARGET=83" >~/printer_data/comms/klippy.serial`

It was extremely time consuming but I think the end result was a good set of thermal calibration samples.

Regarding the Z-offset, as people have noticed, the offset is about 0.12mm which is roughly the thickness of the paper used in the test. My experimentation leads me to believe that all you need to do to correct the Z-offset is to run the manual Z-offset calibration using `PROBE_EDDY_CURRENT_CALIBRATE CHIP=btt_eddy` and apply your print determined offset to the paper test result before accepting. Note that it is really hard to be consistent with the paper test. You do not need to perform the thermal calibration again.

FWIW, I used the following on another computer to make patch which I've been applying to the official Klipper:

`git clone https://github.com/bigtreetech/klipper.git`
`cd klipper`
`git checkout eddy`
`git diff master >~/eddy.patch`

You can apply this patch with `patch -p1 <~eddy.patch` in your klipper folder up until the recent LDC1612 changes that check for an error condition in the eddy current sensor chip. The BTT Eddy appears to always be in an error state during homing so the print aborts.

BTTJUSTIN, 2024-05-29:
Thanks for reporting. We will get this to the software team and provide feedback once they analyze it.

BTTJUSTIN, 2024-06-14:
Hi, thanks for your reporting
I get news from our engineer, The "z offset save" issue will be fixed in the end of weekend (approximately date is 24th )

j-collom, 2024-06-27:
> Hi, thanks for your reporting I get news from our engineer, The "z offset save" issue will be fixed in the end of next weekend (approximately date is 24th )

@BTTJUSTIN  - is this fully fixed and out?

BTTJUSTIN, 2024-07-04:
The eddy has been merge to the klipper .
About the Z offset save issue ,our engineer already has a solution on it ,we need some time to take care of its details.
I will keep on following up .
Thanks for your information.

madsi1m, 2024-07-04:
great! happy to test if needed

looxonline, 2024-07-13:
> great! happy to test if needed

To use the new z-offset feature simply set your eddy up according to our latest guide in the readme document.

maulionc, 2024-12-29:
same issues in my side
need to adjust manually arround zoffset -0.125 at each printing
any solution?

yellowicz, 2025-02-07:
I use the latest configuration and calibrated according to the latest instructions. Every time after finishing printing I have a question whether to save z_offset and after restarting during printing I have to set z_offset again. But I found a solution that I used before and was the most satisfied with - Vitalii TAP. Or Cartographer. Help on Discord, great manual. BTT should learn from them.

maulionc, 2025-02-07:
Hello Marcin do you have more details please

Le ven. 7 févr. 2025 à 10:49, Marcin R. ***@***.***> a écrit :

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

bigtreetech, 2025-02-07:
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

Please try the latest software here: https://github.com/vvuk/eddy-ng/wiki

Closed 2024-07-13.

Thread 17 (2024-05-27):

Klipper reports shutdown

Chaotic3d, 2024-05-27:
At random times during a print I will receive the error: Klipper reports shutdown lost communication with MCU Eddy. I am running Eddy usb on manta e3ez with CB1. I have tried reinstalling Eddy a few different times always with the same end result. All prints fail at some point do to loosing communication with Eddy.

looxonline, 2024-05-28:
@BTTJUSTIN Please escalate this to the engineering team ASAP. No need to wait for the weekly review meeting.

BTTJUSTIN, 2024-05-28:
Thanks for reporting. We will get our engineering  team to look into this.

Elwin232, 2024-05-28:
HI，I  met this question as well.
But it result from the looseconnection the usb cable btween the manta board usb port .Are you able to get the usb id of the eddy via this command ls /dev/serial/by-id at the SSH interface?

BTTJUSTIN, 2024-05-29:
Hi Chaotic3d ,I got some details need to be confirmed with you.
1.Are you able to get the the usb id of the eddy via this command ls /dev/serial/by-id at the SSH interface when  the print to fail at some point during the print ?(Klipper reports shutdown lost communication with MCU Eddy)
2.or it only shows up  the usb id of the eddy  I run a restart ?
3.Could you share me your klippy log file?

Chaotic3d, 2024-05-29:
Let me make sure I understand so once it has failed and shows lost
communication with MCU Eddy ssh into and see if it can see Eddy before
restarting klipper? I will try that as soon as I can I'm waiting on a part
for the printer due to my hotend fan dying due to it going full blast after
klipper lost communication with Eddy.

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

BTTJUSTIN, 2024-05-29:
Hi, Yes, once it has failed and shows lost communication with MCU Eddy,please  ssh into and see if it can see the id of the Eddy before restarting klipper

looxonline, 2024-05-29:
> Let me make sure I understand so once it has failed and shows lost communication with MCU Eddy ssh into and see if it can see Eddy before restarting klipper? I will try that as soon as I can I'm waiting on a part for the printer due to my hotend fan dying due to it going full blast after klipper lost communication with Eddy.
> […](#)
> On Tue, May 28, 2024, 8:06 PM BTTJUSTIN ***@***.***> wrote: Hi Chaotic3d ,I got some details need to be confirmed with you. 1.Are you able to get the the usb id of the eddy via this command ls /dev/serial/by-id at the SSH interface when the print to fail at some point during the print ?(Klipper reports shutdown lost communication with MCU Eddy) 2.or it only shows up the usb id of the eddy I run a restart ? 3.Could you share me your klippy log file? — Reply to this email directly, view it on GitHub <[#17 (comment)](https://github.com/bigtreetech/Eddy/issues/17#issuecomment-2136432832)>, or unsubscribe <https://github.com/notifications/unsubscribe-auth/BIWIXKQKBAIZMHP5RE5G3VDZEVA4HAVCNFSM6AAAAABILEO7L6VHI2DSMVQWIX3LMV43OSLTON2WKQ3PNVWWK3TUHMZDCMZWGQZTEOBTGI> . You are receiving this because you authored the thread.Message ID: ***@***.***>

Could you also tell me a little more about your setup?

What board is being used?
What SBC is being used?
Can you post some pics of your wire routing?
Have you coiled any extra length of the Eddy wire near to high electronic noise sources?
Is the Eddy wire running parallel to high electronic noise sources over a long distance?

BTTJUSTIN, 2024-06-03:
Hi Chaotic3d , do you have time to make a try on this ------once it has failed and shows lost communication with MCU Eddy,please ssh into and see if it can see the id of the Eddy before restarting klipper.@Chaotic3d

wjbillett, 2024-07-09:
Ever figure this out? I have same problem. It happens randomly.  I am using eddy on a hermit crab 2 CAN setup.

bigtreetech, 2024-07-09:
> Ever figure this out? I have same problem. It happens randomly. I am using eddy on a hermit crab 2 CAN setup.

Are you using it (Eddy) over a USB connection? So Eddy and not Eddy Coil.

bigtreetech, 2024-07-09:
@wjbillett @Chaotic3d @Elwin232 We have a new cable that we would like to send to you to test. Please could you send me an email at luke@bigtree-tech.com so that we can get this arranged.

hakankok, 2024-11-23:
I have an eddy sensor that I have been using for about 5 months.The sensor works via USB connected to the Manta M8P platform.However, recently, after performing the table calibration, it stops the printing process by giving a message that the connection is lost during the printing process.However, recently, after performing the table calibration, it stops the printing process by giving a message that the connection is lost during the printing process.

hakankok, 2024-11-23:
I have an eddy sensor that I have been using for about 5 months.The sensor works via USB connected to the Manta M8P platform.However, recently, after performing the table calibration, it stops the printing process by giving a message that the connection is lost during the printing process.When I connect via ssh, it appears that the id is registered. Can you help me solve the problem?

hakankok, 2024-11-23:
I wonder if the problem was solved for the people you sent new cables to?

Closed 2024-06-14.

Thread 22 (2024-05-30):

Z Endstop not working (Must calibrate probe_eddy_current first )

diegomtnz, 2024-05-30:
[printer (eddy).txt](https://github.com/bigtreetech/Eddy/files/15496618/printer.eddy.txt)
Manta-M8P V2 + CB1

mcu(stm32h723xx)
Version: v0.12.0-178-g7e8c7f46

mcu eddy(rp2040)
Version: v0.12.0-166-g957475421
Host(aarch64, 64bit)

Version: v0.12.0-166-g957475421
OS: BTT-CB1 2.3.4 Bullseye

I run the command:
```
LDC_CALIBRATE_DRIVE_CURRENT CHIP=btt_eddy
SAVE_CONFIG
```
add me to printer.cfg:

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

But when I try to home in the z axis I always get this message:

> Must calibrate probe_eddy_current first

ifreislich, 2024-05-30:
You've missed a step. You still need to `PROBE_EDDY_CURRENT_CALIBRATE CHIP=btt_eddy`. You should also re-flash your stm32 mcu with the same version as your host.

krautech has an excellent guide that's easier to follow. Section 3 is where I think you're at.
[krautech's eddy setup guide](https://github.com/krautech/btt-eddy-guide?tab=readme-ov-file#z-endstop)

krautech, 2024-05-30:
Hey,

Make sure you're placing eddy 20mm above the bed when you're doing the LDC_CALIBRATE_DRIVE_CURRENT CHIP=btt_eddy command.

It should auto generate in your printer.cfg the drive current. Yours looks like it's 18 which is very wrong so something has gone wrong in one of your earlier steps.

Reflash firmware and make sure the base of your eddy probe is exactly 20mm above the centre of your bed before you do it.

If you still have issues, come back and let me know

diegomtnz, 2024-05-30:
https://github.com/bigtreetech/Eddy/assets/15325404/349f05ee-21c8-464f-aa40-3d6c529718ce

you can see in video,thanks

diegomtnz, 2024-05-30:
SOLVED:
I need z offset calibration,my printer.cfg now:
#*# <---------------------- SAVE_CONFIG ---------------------->
#*# DO NOT EDIT THIS BLOCK OR BELOW. The contents are auto-generated.
#*#
#*# [probe_eddy_current btt_eddy]
#*# reg_drive_current = 16
#*# z_offset = 0.850
#*# calibrate =
#*# 	0.050000:3219502.999,0.100000:3218637.895,0.150000:3217813.333,
#*# 	0.200000:3217004.405,0.250000:3216097.985,0.300000:3215259.082,
#*# 	0.350000:3214539.599,0.400000:3213774.576,0.450000:3213022.870,
#*# 	0.500000:3212292.122,0.550000:3211543.117,0.600000:3210880.607,
#*# 	0.650000:3210167.339,0.700000:3209524.022,0.750000:3208887.566,
#*# 	0.800000:3208274.048,0.850000:3207685.914,0.900000:3207083.796,
#*# 	0.950000:3206523.057,1.000000:3205914.178,1.050000:3205389.873,
#*# 	1.100000:3204884.781,1.150000:3204363.035,1.200000:3203869.725,
#*# 	1.250000:3203366.151,1.300000:3202853.605,1.350000:3202398.485,
#*# 	1.400000:3201919.492,1.450000:3201480.975,1.500000:3201053.256,
#*# 	1.550000:3200594.807,1.600000:3200165.753,1.650000:3199709.337,
#*# 	1.700000:3199286.008,1.750000:3198910.560,1.800000:3198514.903,
#*# 	1.850000:3198150.712,1.900000:3197758.758,1.950000:3197390.839,
#*# 	2.000000:3197031.282,2.050000:3196679.911,2.100000:3196353.086,
#*# 	2.150000:3196030.354,2.200000:3195703.645,2.250000:3195367.403,
#*# 	2.300000:3195083.491,2.350000:3194790.406,2.400000:3194493.079,
#*# 	2.450000:3194226.396,2.500000:3193900.197,2.550000:3193628.500,
#*# 	2.600000:3193342.894,2.650000:3193092.407,2.700000:3192836.853,
#*# 	2.750000:3192572.462,2.800000:3192304.585,2.850000:3192034.831,
#*# 	2.900000:3191823.611,2.950000:3191589.977,3.000000:3191351.190,
#*# 	3.050000:3191152.487,3.100000:3190903.756,3.150000:3190681.405,
#*# 	3.200000:3190468.077,3.250000:3190259.802,3.300000:3190050.001,
#*# 	3.350000:3189850.527,3.400000:3189653.491,3.450000:3189470.947,
#*# 	3.500000:3189255.185,3.550000:3189065.961,3.600000:3188919.215,
#*# 	3.650000:3188703.005,3.700000:3188511.192,3.750000:3188373.851,
#*# 	3.800000:3188182.358,3.850000:3188007.329,3.900000:3187863.877,
#*# 	3.950000:3187703.384,4.000000:3187579.746,4.050000:3187403.387
#*# calibration_temp = 41.480823

ifreislich, 2024-05-30:
Glad you figured it out. I was trying to tell you that you missed this step.

diegomtnz, 2024-05-30:
> Me alegro de que lo hayas descubierto. Estaba tratando de decirte que te perdiste este paso.

thanks

diegomtnz, 2024-05-30:
> Glad you figured it out. I was trying to tell you that you missed this step.

thanks

Lebeao, 2024-05-31:
Hello, I also need your help, I'm starting to despair, I'm dealing with exactly the same problem "Must calibrate probe_eddy_current first" until then everything is clear,
what happens next with the step "Z Offset Calibration" if that's all When I enter "PROBE_EDDY_CURRENT_CALIBRATE CHIP=btt_eddy" I get the default value 290mm z axis, what happens next?The 290mm is the max height of the z axis, if I enter a different value here it will be displayed. What am I doing wrong, please give me a tip what I can and should do, I'm new to klipper and have just finished building the Voron.
sorry for my English, I had it translated.

best regards Marco

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

ifreislich, 2024-05-31:
You need to complete the `PROBE_EDDY_CURRENT_CALIBRATE CHIP=btt_eddy` step. It doesn't know where zero is so use the dialog and paper test to move the bed or nozzle to set the zero position.

BTTJUSTIN, 2024-06-04:
Thanks for reaching out. Our support team does not operate using the GitHub platform but we would be happy to help you via email based ticketing system. Please visit https://biqu.equipment/pages/technical-support and submit a ticket and we will be in touch with you soon.

Closed 2024-06-04.

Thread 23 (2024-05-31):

Error during homing z: Eddy current sensor error

lusl13, 2024-05-31:
when is eddy mcu temp below 40°C, works fine. but when is above 40°C, is problem with homing z axis. console says "Error during homing z: Eddy current sensor error"
[klippy (3).log](https://github.com/user-attachments/files/15515403/klippy.3.log)

ifreislich, 2024-05-31:
What's your value for `reg_drive_current` in the saved config section? The autocalibration doesn't pick the best value. You probably need to increase it by 1, but changing the drive current requires full Z offset and temperature drift calibration.

krautech, 2024-05-31:
> when is eddy mcu temp below 40°C, works fine. but when is above 40°C, is problem with homing z axis. console says "Error during homing z: Eddy current sensor error"
> [klippy (3).log](https://github.com/user-attachments/files/15515403/klippy.3.log)
>

I'll look through your klippy logs when I'm at a PC.

In the meantime go over your USB connections and reinstall the firmware from the start to see if it makes a difference.

Is it consistent? Like anything over 40c it won't home? Or just sometimes?
Does it ever happen UNDER 40c?

krautech, 2024-05-31:
> What's your value for `reg_drive_current` in the saved config section? The autocalibration doesn't pick the best value. You probably need to increase it by 1, but changing the drive current requires full Z offset and temperature drift calibration.

Changing the drive current after he has done temperature drift will throw out all the temperature drift calculations, I don't recommend this.

ifreislich, 2024-05-31:
> Changing the drive current after he has done temperature drift will throw out all the temperature drift calculations, I don't recommend this.

It can always be set back to the original value if it doesn't solve the higher temperature homing.

lusl13, 2024-06-01:
@ifreislich reg_drive_current = 15
@krautech

37°C ok
39°C ok
40°C ok
41°C ok
42°C ok
43°C ok
44°C ok
45°C ok
46°C not ok - Error during homing z: Eddy current sensor error
47°C not ok - Error during homing z: Eddy current sensor error

everything worked fine with klipper version v0.11, but after update to v0.12 have this problem.

i cant make temp compensation calibration. when i send " PROBE_DRIFT_CALIBRATE PROBE=btt_eddy TARGET=80 STEP=5" to console, klipper want to z-offset calibration..

i dont use this command:
git remote add eddy https://github.com/bigtreetech/klipper
git fetch eddy
git checkout eddy/eddy

because when i use that command, klipper wont start because klipper in that btt url is older than my mcus

krautech, 2024-06-01:
I think I've seen your messages via Facebook

You need to go and update all your mcus with the BTT version of klipper. So run BTT klipper, then go and do all the make menuconfig etc to rebuild your firmware for your devices using the BTT version of klipper as the base

lusl13, 2024-06-01:
@krautech i updated all to
host: v0.12.0-166-g957475421-dirty
all mcus: v0.12.0-166-g957475421

now testing...
47°C ok
50°C ok
60°C ok

so.. its working fine. thank you

krautech, 2024-06-01:
Great to hear!! Glad we could get it sorted for you.

BTTJUSTIN, 2024-06-04:
Hi，it is glad to hear that you figured it out

Closed 2024-06-04.

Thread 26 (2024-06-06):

Need to home Z to calibrate, need to calibrate to home Z

helloITdepartment, 2024-06-06:
I'm up to section 3, step 22 of the readme, where it says to run `PROBE_EDDY_CURRENT_CALIBRATE chip=btt_eddy`. Doing so gives the familiar gui prompt with the + and - to move the nozzle up and down, but clicking either aborts and gives me the error `Must home axis first: 165.000 130.000 10.300 [0.000]`. Fair enough, I'll just home all the axes. But when it gets to homing Z, it gives me the error `Must calibrate probe_eddy_current first` (homing X and Y without Z work fine) which seems to be this endless cycle. Unless I'm missing something? Either from the documentation or otherwise?

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

krautech, 2024-06-06:
G28 X Y

And then

PROBE_EDDY_CURRENT_CALIBRATE chip=btt_eddy

helloITdepartment, 2024-06-06:
Yeah I did that, sorry the G28 X Y was cut off in the first image. Just ran it again, and still same issue

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

krautech, 2024-06-06:
Do you have any custom homing macros or anything?

helloITdepartment, 2024-06-06:
Nope, just double checked. I'm trying to figure out the issue, but I can't seem to see from the code when the z homing was expected to happen. Unless the manual z offset isn't supposed to need calibration? But that doesn't sound right

helloITdepartment, 2024-06-07:
Thought it might have had to do with the fact that I previously had a BLTouch installed, but I removed all reference to it in the printer.cfg and even just unplugged it just to be sure. Should I reinstall the original Z endstop microswitch just so it has something to home Z against? Does Eddy not do Z homing? Isn't that the point of the `endstop_pin: probe:z_virtual_endstop` line?

krautech, 2024-06-07:
It definitely does z homing..I use it all day.

Something in your config is causing it to register the z height wrong, which throws out the calibration from being able to be adjusted.

Can you upload your config? Thanks

helloITdepartment, 2024-06-07:
Sure, here's both
I have the file for eddy separated out for modularity so I've included both (also made into txt so GH will accept it)
[eddy.txt](https://github.com/user-attachments/files/15737527/eddy.txt)
[printer.txt](https://github.com/user-attachments/files/15737528/printer.txt)

krautech, 2024-06-07:
remove `z_offset: 1.0` from eddy config and also you have

`[bed_mesh]`
and
`[safe_z_home]`

sections in both your configurations, choose whichever is more appropriate for your setup.
(My advice, use the one in Eddy but adjust your mesh_min and mesh_max to your appropriate size.

BTTJUSTIN, 2024-06-07:
Thanks for reaching out. Our support team does not operate using the GitHub platform but we would be happy to help you via
email based ticketing system. Please visit https://biqu.equipment/pages/technical-support and submit a ticket and we will be in touch with you soon

krautech, 2024-06-07:
> No luck unfortunately I'm just trying to understand the process. When running the `PROBE_EDDY_CURRENT_CALIBRATE CHIP=btt_eddy`, is it first supposed to go down and probe Z to home and then figure out what the offset it? I think that's how I remember the probe_calibrate for the BLTouch working, but my Eddy doesn't do that

No, its supposed to stay motionless at the location you start the calibration and then youre meant to adjust it down to paper height yourself. Its slightly different to the BL touch calibration

helloITdepartment, 2024-06-07:
Hmm curious. Then I guess the question is why does it require Z to be homed if it's just going adjust it with the offset? Or rather, how is it supposed to know where Z0 is? Does the Eddy just take a reading from wherever it is and go "oh looks like the bed is 20mm away"? In which case wouldn't some calibration need to happen first?

krautech, 2024-06-07:
Painfully annoying but yes lol

You're supposed to home X and Y and then Z will be at "0" then you lower it to your lowest Z point you have configured.

So start the calibration as close to the bed as you can with a little bit of wiggle room. Otherwise you'll hit the movement out of range error.

krautech, 2024-06-07:
I have a print finishing in an hour or so, once its finished I'll video the process.

krautech, 2024-06-07:
Could you try comment out your

`screw_tilt_adjust`

and see if it makes any difference

helloITdepartment, 2024-06-07:
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

Then I think we've narrowed down the problem. Mine doesn't seem to do that bit where it says "okay we're doing the calibration, let me mark this position as Z0 and tell the system that Z is homed"

PavelTajdus, 2024-06-09:
You can use Klippers `SET_KINEMATIC_POSITION Z=0` and even with negative number, so than your printer think its homed. But be carefull with moving the printers toolhead.

https://www.klipper3d.org/G-Codes.html?h=set_kinematic_position#set_kinematic_position

helloITdepartment, 2024-06-16:
> You can use Klippers `SET_KINEMATIC_POSITION Z=0` and even with negative number, so than your printer think its homed.

So this worked to get the Eddy to calibrate. Then I `SAVE_CONFIG`ed, and went to rehome XYZ to see if it worked, and:
`Error during homing z: Eddy current sensor error`

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

Even went back and recalibrated the current (section 2 step 17) and still same issue

krautech, 2024-06-16:
I'd stop bothering

There's too many issues with BTT eddy to devote time and energy to it, get a beacon or my preference cartographer, and be done with it.

Closed 2024-06-14.

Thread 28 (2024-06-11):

No valid measurements found at coordinate.

bigblzrd, 2024-06-11:
I've been banging my head against a wall with this thing for a couple of weeks now.

First off I had zero success with the temperature calibration and persevered with it for days and it wouldn't keep it's Z offset reliably or more often than not would just error on it's first home with the bed at temp.

After giving up with that I'm now using a Z endstop and I thought after installing that, everything would be smooth sailing. Instead I'm constantly met with a 'No valid measurements at coordinate' error every single time I do a mesh. It's definitely not because it's too close to an edge, I've tried countless values for my bed mesh min and max XY but without fail it throws the error wherever the toolhead starts the mesh.

I'm completely out of ideas to find a solution for this, I can't even find documentation on the error itself as it doesn't appear to exist in the source code for BTTs fork of Klipper or the main branch.

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

krautech, 2024-06-11:
Hey, sounds about right lol I'll try help where I can but unfortunately you're not going to get any help from BTT here other than to "email a ticket to them"

- What printer is it?
- What bed type are you using?
- Does it have a giant magnetic sticker? Small magnets?
- When you place your toolhead over X20 Y25 can you show me a photo of where it sits?
- Can you please upload your printer.cfg (you'll need to compress it as a zip to upload it)

I'm not actively working on Eddy anymore, as I think BTT has more or less abandoned it until Kevin @ Klipper implements his probe scripts fully and I personally had way to many issues for it to be worth it not to mention the 30-40 people I've know helped get it "running" with work arounds and missing features.

bigblzrd, 2024-06-11:
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

Hey man!

It's an Enderwire with the standard Creality bed and full magnetic sheet (not embedded magnets).

I've played with moving the min XY in loads to make sure it wasn't caused by it being close to an edge and yeah wherever the minimums set it'll always error :(

My config might be a little bit messy in some areas where I've been experimenting with things so I apologise in advance. Every sections labeled though hahah

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

[printercfg.zip](https://github.com/user-attachments/files/15794665/printercfg.zip)

krautech, 2024-06-11:
Even if you set

```
mesh_min: 100,100
mesh_max: 180,180
```

Does it give the same no measurement?

bigblzrd, 2024-06-11:
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

Yep so I just tried and it errors here...

```No valid measurements found at coordinate : [100.0, 75.0]```

krautech, 2024-06-11:
Weird, it shouldn't even be scanning 100, 75

Hmm,

My only real suggestion is starting completely fresh with your printer.cfg
Which, as someone with a similar modified printer, is easier said than done.
Honestly, unless someone has an immediate solution, I wouldn't bother
trying to wrap your head around it anymore unless you don't care if your
printer is unusable?

Could be firmware, could be hardware. The error code doesn't help at all,
except to say it's not getting anything whilst scanning lol

My final thought is this..

Delete [bed_mesh] and [probe_eddy_current] sections from the very bottom of
your printer.cfg

Redo the calibration steps for eddy. DONT do the temperature compensation
steps. But you must do the z height calibration which looking at it, you
seem to not have configured.

Then once that's finished, it will add a more detailed [probe_eddy_current]
section, and then try run a bed mesh.

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

bigblzrd, 2024-06-11:
> Weird, it shouldn't even be scanning 100, 75 Hmm, My only real suggestion is starting completely fresh with your printer.cfg Which, as someone with a similar modified printer, is easier said than done. Honestly, unless someone has an immediate solution, I wouldn't bother trying to wrap your head around it anymore unless you don't care if your printer is unusable? Could be firmware, could be hardware. The error code doesn't help at all, except to say it's not getting anything whilst scanning lol My final thought is this.. Delete [bed_mesh] and [probe_eddy_current] sections from the very bottom of your printer.cfg Redo the calibration steps for eddy. DONT do the temperature compensation steps. But you must do the z height calibration which looking at it, you seem to not have configured. Then once that's finished, it will add a more detailed [probe_eddy_current] section, and then try run a bed mesh.
> […](#)
> On Wed, 12 June 2024, 9:00 am blzrd, ***@***.***> wrote: Even if you set mesh_min: 100,100 mesh_max: 180,180 Does it give the same no measurement? Yep so I just tried and it errors here... No valid measurements found at coordinate : [100.0, 75.0] — Reply to this email directly, view it on GitHub <[#28 (comment)](https://github.com/bigtreetech/Eddy/issues/28#issuecomment-2161736101)>, or unsubscribe <https://github.com/notifications/unsubscribe-auth/ABIZAY3MN3OKONUPNBCXKKDZG56SVAVCNFSM6AAAAABJE35YTWVHI2DSMVQWIX3LMV43OSLTON2WKQ3PNVWWK3TUHMZDCNRRG4ZTMMJQGE> . You are receiving this because you commented.Message ID: ***@***.***>

See I wondered about the Z calibration stuff, if I'm using a Z endstop is that still necessary?

Until the thermal stuff gets sorted I planned to treat it as if I had the Coil version. As you said though I think I'll just have to start everything Eddy and bed mesh related from scratch and pray something fixes itself. I'll switch back to the main Klipper build and completely start again with reflashing etc.

If none of that works then I'm well and truly lost lol. I'll give it a go in the morning (It's midnight here) and report back if I get any further.

Really appreciate the input so far though, thank you!

krautech, 2024-06-11:
Yeah you need to complete all steps up until step 26.

It still needs to know where eddy is in relation to your nozzle so that it can provide a bed mesh.

So my guess is now 90% this is what you're missing from been able to complete a bed mesh

bigblzrd, 2024-06-12:
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

So update, I've got the thing printing.

So the issue turned out to be exactly what you said, all I needed to do was calibrate the Z offset of the probe and I haven't actually touched anything else or reflashed. However I've discovered if I do that Z calibration with the bed cold, as soon as it's at temp and I do a mesh it throws the error. If I do the Z calibration at temp it meshes fine so I'm now wondering if I should just live with it and hope it stays consistent at meshing when its at temp or still start from scratch and maybe iron that small caveat out.

In all honesty I don't feel like I'll be able to get it much better so while I wait for the full Klipper implementation I think it's best to just cross my fingers and make the most of it while it works hahah

krautech, 2024-06-12:
Glad to hear it's mostly sorted!!

Calibrate it while at your print temp, that's what I did while still using eddy and for the most part it worked.

BTTJUSTIN, 2024-06-14:
Thanks for reaching out. Our support team does not operate using the GitHub platform but we would be happy to help you via email based ticketing system. Please visit https://biqu.equipment/pages/technical-support and submit a ticket and we will be in touch with you soon.

JustACrouton, 2024-06-27:
I had the same problem. idk what fixed it but make sure "horizontal_move_z: 2"
and try running the commands in the Klipper documentations instead of the BTT ones. ("BED_MESH_CALIBRATE METHOD=scan")

Closed 2024-07-13.

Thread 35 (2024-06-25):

How to flash Klipper on Eddy Coil?

ilio, 2024-06-25:
I read the instructions, searched on Google, but still couldn't figure out how to connect the device via USB. The package only included an I2C cable.

ilio, 2024-06-25:
As I understand it, Klipper on Eddy Coil does not require flashing because it does not contain a controller.

Closed 2024-06-25.

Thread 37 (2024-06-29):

z tilt adjust readings way off.

crackmonkeyy, 2024-06-29:
I have a strange issue with eddy, it homes and generates bed meshs fine but when I do z tilt adjust it gives crazy readings. with the bed a few mm away it will say things like 90+plus mm then next spot 60 something and ever time it's completely random.
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

eselcuker, 2024-07-03:
i have same issue, impossible to make z tilt, because of this cant print anything, any solution ?

crackmonkeyy, 2024-07-03:
> i have same issue, impossible to make z tilt, because of this cant print anything, any solution ?

i managed to get the z tilit working by setting the z offset to 0, there seams to be a bug which kept adding my new z_offset to the old one and eventually my z_offset was at 90 odd mm and that messed with the z tilit. the only was i can get the z_offset working properly was offsetting the gcode using prusaslicers z_offset feature.

eselcuker, 2024-07-03:
Thanks for your repply but when i make z offset 0 under probe settings in cfg i am getting Invalid probe_eddy_current height error cant do z tilt

looxonline, 2024-07-03:
@eselcuker @crackmonkeyy @
Some questions and some things to consider:

Question(s):
- What printers are you all using?

Consider:
- The Eddy will read reliable data up to about 15mm before the edge of the bed. Make sure that you are not setting your probing points within that safety boundary for the z-tilt adjust.

eselcuker, 2024-07-04:
> * adjust

mine is a voron trident, BTT EDDY is a fully bullshit, i took it apart, threw it away and i don't plan on using it again, useless product. i did dispute order on aliexpress,

looxonline, 2024-07-04:
> > * adjust
>
> mine is a voron trident, BTT EDDY is a fully bulls***, i took it apart, threw it away and i don't plan on using it again, useless product. i did dispute order on aliexpress,

How close to the edge of the bed were you trying to probe?

crackmonkeyy, 2024-07-06:
hey, I have mecury zero g and the issue for me was the z offset being ignored by eddy, each time I would lower the nozzle -0.5mm and  it save to the config. but when the next print starts its around 0.5mm to high from the bed again. i lowered nozzle again and saved then eventually my z offset was near 90mm. which then caused the z tilt errror. to reproduce the issue set z offset to 90mm at the bottom of the printer.cfg . as a work around ive set the offset to 2mm for eddy in printer.cfg and used prusaslicer to modify the gcode to adjust the z offset. im still not getting a reliable reading for eddy as a z endstop though, it's not reliable at all. 😔 hopefully u guys can get it sorted with an update?

bigtreetech, 2024-07-06:
> hey, I have mecury zero g and the issue for me was the z offset being ignored by eddy, each time I would lower the nozzle -0.5mm and it save to the config. but when the next print starts its around 0.5mm to high from the bed again. i lowered nozzle again and saved then eventually my z offset was near 90mm. which then caused the z tilt errror. to reproduce the issue set z offset to 90mm at the bottom of the printer.cfg . as a work around ive set the offset to 2mm for eddy in printer.cfg and used prusaslicer to modify the gcode to adjust the z offset. im still not getting a reliable reading for eddy as a z endstop though, it's not reliable at all. 😔 hopefully u guys can get it sorted with an update?

I know exactly what was happening with your machine and why. I am 100% confident that you can get great results out of it by following the steps below:

1. Bring in all of the latest macros from our latest sample.cfg file.
2. Perform the eddy probe calibration and thermal calibration again.
3. Have a read through this to understand how a z-offset works with an Eddy current probe and why your changing and saving did what it did: https://gist.github.com/bigtreetech/484380b26be613b9139bc537510393df

Please let me know the results after you apply point 1 and 2. I am sure they will solve your issues.

crackmonkeyy, 2024-07-10:
hey @bigtreetech , Thanks for your help, I tried your suggestions today.
1. i loaded all the new macros from the beta config. only issue i had was due to me having a ecrf v2 and the multiple call for save_variables but that was a simple fix to merge the folders.
2. i redid the probe calibration and thermal calibration, i had slight issues with the thermal compensation calibration as my printer is open air and eddy only gets to 46 degrees c. it only did 3 calibrations even when i changed the steps to every 2 degrees? the thermal compensation seams to be working fine though so not a big issue.
3. eddy was saving the z offset in printer.cfg, the new beta is saving it in the save_variables folder correctly now and loads it when starting a print correctly.

looxonline, 2024-07-13:
Closing since this seems to be resolved now.

Closed 2024-07-13.

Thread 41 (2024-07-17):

Triggers above bed

sanpedrox2, 2024-07-17:
Hi.
when trying to get my eddy working i have hit a wall.
after the temperature tuning step the eddy triggers a few cm above the bed when homing and ofc cant get a scan off the bed from that height. if i try printing obviously that doesnt work either from a few cm above the bed :)

as the bed cools down it triggers closer and closer, i get a feeling that some numbers are calculated wrong somewhere.

any tips would be greatly appreciated :)

looxonline, 2024-07-17:
I feel like your thermal tuning must be off. Are you sure that you followed the guide 100%? I would suggest:
1. Back up your klipper config.
2. Delete the autosaved thermal compensation at the end of the klipper config so that it has no effect.
3. Check if you have the same issue of it triggering up cm above the bed when it is hot.
4. If the problem has gone away then there was something that was not done right during the thermal comp step. Remember that you need to run a paper level at each point during the thermal comp.

sanpedrox2, 2024-07-17:
i did delete the settings and started over, with the same result. didnt try it inbetween though.
and yes, i know to do the papertest, i have followed the guide 100% both of the times. especially the second ;)

gonna have a go with a clean slate and see

sanpedrox2, 2024-07-17:
ok.. it does increase. but not so extreme. just a couple of mm instead of cm. guess ill retry the temp tune :/

looxonline, 2024-07-17:
> ok.. it does increase. but not so extreme. just a couple of mm instead of cm. guess ill retry the temp tune :/

I have noticed that bad data in the autosave part of the config can really mess with things. Maybe it is best to just clear out the whole autosave part that has anything to do with probes and start fresh.

sanpedrox2, 2024-07-17:
yes, i did that several times now. still get the same result.
trying to home after a save_config, results in "endstop z still triggered after retract". the nozzle is 2 cm above bed at this point because of z lift before home.

eddy at 60c triggers a few cm above bed. at 55 its about one cm.

pretty sure it doesnt use temperature compensation at all

bigtreetech, 2024-07-17:
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

Could you upload your config files to pastebin and post them. Please also upload some pictures of your installation here, clearly showing the height of the eddy above the nozzle.

sanpedrox2, 2024-07-17:
https://pastebin.com/xZbrmwja
https://pastebin.com/FrzJGb6b

sanpedrox2, 2024-07-17:
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

looxonline, 2024-07-17:
Thanks. It is super late here now. I'll have a look in the morning.

sanpedrox2, 2024-07-17:
thank you :)

sanpedrox2, 2024-07-18:
i think i may have fixed it by changing #*# reg_drive_current = 15
to #*# reg_drive_current = 16
as i saw some others had succes with that.

so far it seems to be working and not throwing any errors when homing/meshing

looxonline, 2024-07-18:
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

Thanks for letting us know about the resolution. We have not seen this sort of behaviour on other installations so I will add something to the FAQ to share your experience with others.

sanpedrox2, 2024-07-27:
No problem :-)
i can also report that i did try to revert  ## reg_drive_current = 16 back to 15 out of curiosity. to check if it really was the solution as i had tinkered with a few other settings.

Can confirm that the problem came back instantly with 15, and dissapeared as soon as i went back to 16.
i did the current calibration with eddy 20mm from the bed as per the instructions and got 15 every time. its not right in my case atleast 👍

Closed 2024-07-18.

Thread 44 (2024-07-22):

Failed calibration - frequency not increasing each step

JonasBouchard, 2024-07-22:
When I run `PROBE_EDDY_CURRENT_CALIBRATE_AUTO CHIP=btt_eddy` , I get the error `Failed calibration - frequency not increasing each step` . I already ran through drive current calibration and the z offset between the nozzle and the probe is very small.

jeffstark, 2024-07-24:
The command isn't working for me either. After I accept the paper test in the very first step, the console says `temperature_probe btt_eddy: calibration aborted`

If I proceed by changing the bed and nozzle temp, the script never asks me to do the paper test again.

BTTJUSTIN, 2024-07-26:
Thanks for reaching out. Our support team does not operate using the GitHub platform but we would be happy to help you via email based ticketing system. Please visit https://biqu.equipment/pages/technical-support and submit a ticket and we will be in touch with you soon

bigtreetech, 2024-07-26:
@BTTJUSTIN This is not a support request. This is a problem and it should follow that flow. I am reopening it and I want you to please follow the correct flow.

bigtreetech, 2024-08-05:
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

This is not the same command that the OP is talking about. You are speaking about thermal comp and the OP is speaking about the frequency mapping. Have you performed your frequency mapping before you try to perform your thermal comp?

bigtreetech, 2024-08-05:
> When I run `PROBE_EDDY_CURRENT_CALIBRATE_AUTO CHIP=btt_eddy` , I get the error `Failed calibration - frequency not increasing each step` . I already ran through drive current calibration and the z offset between the nozzle and the probe is very small.

Some questions:

1. Are you using Eddy or Eddy coil?
2. What was the result of the LDC calibration? Should be between 14 and 16.

bigtreetech, 2024-08-13:
> When I run `PROBE_EDDY_CURRENT_CALIBRATE_AUTO CHIP=btt_eddy` , I get the error `Failed calibration - frequency not increasing each step` . I already ran through drive current calibration and the z offset between the nozzle and the probe is very small.

Closing because we are not getting any response.

SinglerGold2, 2024-10-05:
Well, I do have the problem now...

BTT Eddy USB
LDC Calibration =  15

MJD19994, 2024-10-17:
I am having the same issue with an Eddy USB, it fails the calibration every time and my LDC Calibration came in at 16 within the range of the above comment. I submitted a support ticket but it so far that has been very little help. It seems like my printer is losing steps on the z axis and not actually moving as it should during the calibration. The lost steps only happen during the calibration action, during normal operations my z axis moves as it should.

Sharkooon42, 2024-12-10:
I am experiencing the exact same issue as described in the last comment. My Eddy USB sensor fails calibration every time. The Z-axis seems to lose steps during the calibration process and doesn’t move correctly, even though it operates perfectly fine during normal use. My LDC calibration also resulted in a value within the correct range, so I would rule out a hardware issue.

It would be great if someone could share a solution or suggest any approaches to resolve this problem. I’ve already tried adjusting some settings, but without success. Are there any further tips or updates that address this issue?

AleCo3lho, 2024-12-12:
I am having the same problem, Eddy Coil. LDC 16

jotaperez3, 2025-01-19:
Was anyone able to solve this problem, I have not been able to solve it in any way.

AleCo3lho, 2025-01-19:
> Was anyone able to solve this problem, I have not been able to solve it in any way.

In my case I am using a Eddy Coil so it may be different from yours, but basically it was a problem with the wiring.

Closed 2024-08-13.

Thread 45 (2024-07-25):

Invalid probe_eddy_current height

Zaskeller, 2024-07-25:
probe is 1.2mm above nozzle. done probe calibrate on the EDDY USB version. python is updated klipper fork is used and have tested without klipper fork still get error.

"Invalid probe_eddy_current height"

notable this error triggers instantly if say doing a screw tilt calculate or bed mesh. if machine is homed. doing a bed mesh moves the probe to the first point but the error triggers before the probe has moved.

have this issue on two machines i have tested every thing i can think of and just can not get it working.

bigtreetech, 2024-07-25:
Please try to raise the probe up to about 4mm above the nozzle and then try again. Please let me know how it goes. I believe that in some cases users actually need to mount their probes higher than usual and if so then I would like to add this to the manual/guide.

flavio-costa, 2024-08-09:
My Btt Eddy USB started to present the same problem, even placing it 4mm from the table, redoing the entire configuration from scratch, it doesn't work.

flavio-costa, 2024-08-09:
Apparently, I managed to solve my problem.
I went to printer.cfg and uncommented the z offset line in: [probe_eddy_current btt_eddy]
and I redid the calibration, it worked normally again.

bigtreetech, 2024-08-13:
> Apparently, I managed to solve my problem. I went to printer.cfg and uncommented the z offset line in: [probe_eddy_current btt_eddy] and I redid the calibration, it worked normally again.

Yes, this setting is required.

bigtreetech, 2024-09-26:
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

I think I'll try to add this point to the FAQ to let people know that it's better to keep it in the standard config than in the do not touch section.

serbiansky, 2024-10-23:
What should be the value for z_offset then as I am facing issues with my nozile is to low what ever the settings in z_offset I put?

DaveTheBuskerUK, 2024-10-23:
> What should be the value for z_offset then as I am facing issues with my nozile is to low what ever the settings in z_offset I put?

You tune that live, you don't enter a value into the printer.cfg

The tool is called PROBE_CALIBRATE you can launch it by typing that command into the console

Here's the Klipper docs page for it - https://www.klipper3d.org/Probe_Calibrate.html

Does that help ?

serbiansky, 2024-10-24:
I am trying to use Eddy on my Ender 3v2 modified printer as probe and z end stop and in the configuration example they added z-offset=2.5, if I comment this part then klipper is complaining. Whatever the value I put in the probe is to low. Yesterday I put 2.5 and nozzle banded the bed. If I reduce to range 0.1-1.5 is to low and 0.0 klipper is complaining. Obviously I am doing something wrong.
https://github.com/bigtreetech/Eddy/blob/master/sample-bigtreetech-eddy-homing.cfg

motion-mind, 2025-02-06:
I'm still getting this error. When I run PROBE_EDDY_CURRENT_CALIBRATE_AUTO CHIP=btt_eddy, the height that it starts with is 346mm no matter what. Shouldn't this start closer to 0? After I complete this calibration and try to HOME, the toolhead position says it's at 500mm+ and I get the **Invalid probe_eddy_current height** and HOME fails.

Closed 2024-08-13.

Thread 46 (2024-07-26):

PROBE_DRIFT_CALIBRATE Problem

ej8g82p, 2024-07-26:
I'm having an issue performing the temperature calibration. After running PROBE_DRIFT_CALIBRATE PROBE=btt_eddy TARGET=50 STEP=5 and making the last adjustment, I get a "probe_eddy_current btt_eddy: invalid calibration detected, curve at index 5 overlaps previous curve at temp 75C" message.
Anybody else run into this problem before, or have any ideas?

jeffstark, 2024-07-26:
At least a couple of us are experiencing this issue with no solution in sight. BTT keeps closing support tickets and telling us to email them.

ej8g82p, 2024-07-26:
I see. Thanks for the heads up

bigtreetech, 2024-07-26:
> At least a couple of us are experiencing this issue with no solution in sight. BTT keeps closing support tickets and telling us to email them.

There is *one* issue that has been closed like that with the others having received thorough discussion and assitance.

ej8g82p, 2024-07-26:
What's the proper way to go about getting assistance?

Brenddpaula, 2024-07-27:
Hey, I was having the same problem and I've solved it by erasing the saved configs related to eddy from my printer.cfg and started the process again.
What I've noticed is that this issue was happening when the value of testz during temperature raise were lower than the previous ones. After deleting the config and starting all again it did not find any reductions in value while raising the bed temperature and was able to complete the process.

ej8g82p, 2024-07-27:
> Hey, I was having the same problem and I've solved it by erasing the saved configs related to eddy from my printer.cfg and started the process again. What I've noticed is that this issue was happening when the value of testz during temperature raise were lower than the previous ones. After deleting the config and starting all again it did not find any reductions in value while raising the bed temperature and was able to complete the process.

Thank you for you help. I've tried doing that multiple times, but it still fails for me. What I'm confused about is that it detects a problem with a previous curve at 75C, and I can't seem to get my eddy to go past 54C when doing the calibration 🤷‍♂️

ph0tic, 2024-08-10:
im having this problem too

jeffstark, 2024-08-10:
> im having this problem too
>
>

Same here

bigtreetech, 2024-08-12:
Hey all. We are looking into this and will update this thread as soon as we have a better understanding of what may be causing this.

bigtreetech, 2024-08-12:
@jeffstark @ej8g82p @ph0tic @Brenddpaula Could you all let me know what temp range you are trying to calibrate to (the command you are initially sending) and what temperature you are actually able to hit during the calibration?

Arksine, 2024-08-12:
Hi everyone, I have pushed a branch that should help alleviate this issue.

https://github.com/Arksine/klipper/tree/dev-temperature_probe-20240812

The problem is due to the relatively low range you are able to achieve during calibration.  The calibration is capable of extrapolating values outside of the calibration range, however if your printer is not enclosed it is unlikely that the probe's coil will ever reach temperatures that high.  This patch adds a new `max_valid_temp` option that defaults to 60C.  This value should allow you to pass validation.

If some users could test this branch and confirm it resolves their issue I will create a pull request for it.

jeffstark, 2024-08-12:
> @jeffstark @ej8g82p @ph0tic @Brenddpaula Could you all let me know what temp range you are trying to calibrate to (the command you are initially sending) and what temperature you are actually able to hit during the calibration?

I'm just following the guide step by step, so whatever is in the official guide is what I did. I see that we can now use mainline klipper, so im gonna wipe the eddy stuff again and try it from scratch. If that doesnt work, I'll try Arksine's build.

ej8g82p, 2024-08-12:
> @jeffstark @ej8g82p @ph0tic @Brenddpaula Could you all let me know what temp range you are trying to calibrate to (the command you are initially sending) and what temperature you are actually able to hit during the calibration?

I think the max temp I was able to get to is around 54C, and I was calibrating to 50C with the last step being around 51-52C

bigtreetech, 2024-08-12:
> > @jeffstark @ej8g82p @ph0tic @Brenddpaula Could you all let me know what temp range you are trying to calibrate to (the command you are initially sending) and what temperature you are actually able to hit during the calibration?
>
> I think the max temp I was able to get to is around 54C, and I was calibrating to 50C with the last step being around 51-52C

Yea then your cali range would have been so low that the validation algo would have hit some errors when trying to validate the extrapolated results around 75C and upwards. The new branch should fix it. Once you and others validate, Arksine will issue the PR.

ej8g82p, 2024-08-12:
Sounds like @Arksine is dead on with the solution. I most definitely can't reach the higher temperatures with my max being around 54C. I will try the 60C max branch and will report back as soon as I get a chance

jeffstark, 2024-08-12:
I'm trying @Arksine's klipper build, and Im up to step 32 in the guide, which is what I couldn't proceed beyond before.

Step 32 is enter `PROBE_DRIFT_CALIBRATE PROBE=btt_eddy TARGET=56 STEP=4` in the console. When I do that it now says `Unknown command:"PROBE_DRIFT_CALIBRATE"`

It's entirety possible I messed up somewhere, but that's where I am. With the btt klipper fork, I could enter this command, but never finish the calibration steps. This build seems to be missing it, unless I took a wrong turn somewhere.

bigtreetech, 2024-08-12:
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

Ah wait. I forgot to update that command. One sec...read the guide in two minutes.

jeffstark, 2024-08-12:
> Ah wait. I forgot to update that command. One sec...read the guide in two minutes.

I can confirm that @Arksine's klipper build along with the new command `TEMPERATURE_PROBE_CALIBRATE PROBE=btt_eddy TARGET=56 STEP=4` works.

I have finally completed this step.

Thanks!

bigtreetech, 2024-08-12:
Going to close this one out for now and ask Arksine to send through a PR.

Arksine, 2024-11-25:
> The link for the branch does work anymore, can you update it? Thanks in advanced

The changes in that branch were merged to Klipper master, so the branch was deleted.

1jgrodrigues, 2024-11-25:
> > The link for the branch does work anymore, can you update it? Thanks in advanced
>
> The changes in that branch were merged to Klipper master, so the branch was deleted.

Do you mean BTT version of klipper or the oficial klipper version?
Were do you configure the option max_valid_temp?

Arksine, 2024-11-25:
> Do you mean BTT version of klipper or the oficial klipper version?
Were do you configure the option max_valid_temp?

The official Klipper branch.  The `max_validation_temp` option is configured in the [temperature_probe](https://www.klipper3d.org/Config_Reference.html#temperature_probe) section.

Closed 2024-08-12.

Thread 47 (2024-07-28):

homing issues after PROBE_DRIFT_CALIBRATE

cjhmdm, 2024-07-28:
Using the USB version of Eddy. Going through the config steps in this wiki. After running PROBE_DRIFT_CALIBRATE, when I home my z gets set to 99.900 and I am unable to manually (or otherwise) move it to 0

cjhmdm, 2024-07-28:
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
screenshot of the issu. Notice Z is set to 99.900, this is immediately after homing and after going through PROBE_DRIFT_CALIBRATE

CzarnyRafal, 2024-08-08:
It looks like there is problem with saving variables.
Are you using this Zoffset-beta config file?

I have similar problem, when you copy this "Result..." value (without minus) to the variables.cfg file it should set it near zero.

bigtreetech, 2024-08-08:
> Using the USB version of Eddy. Going through the config steps in this wiki. After running PROBE_DRIFT_CALIBRATE, when I home my z gets set to 99.900 and I am unable to manually (or otherwise) move it to 0

There is something messed up with your calibration. It thinks that it is at a crazy low value when it is just probing the bed. Could you do the following:

1. Clear out anything in the klipper auto save part of your config that is related to probing or the eddy. Make sure that you are careful about leaving the format in a way that klipper can still read the other parts of the autosave after you have removed that stuff.
2. Start with the LDC calibration and then run the mapping calibration. Don't run the thermal comp just yet.
3. Pop your config file into a pastebin link as soon as you have done the mapping and send the link here.
4. Run the thermal comp.
5. Pop the new config file into another pastebin link as soon as you are done with the thermal comp and then send the link here.
6. Look inside variables.cfg and also copy that into a pastebin link.

cjhmdm, 2024-08-08:
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

Hello,

After having gone through the entire calibration process from start to finish several times, the z-position being set to 99.900 specifically happens after running the thermal compensation, each and every time. When I have some more time available later today, I'll go through and post back the information you're requesting.

bigtreetech, 2024-08-08:
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

OK, this is useful info. There may be a bug with the thermal comp algo that we need to investigate. Thanks for working with us on it.

cjhmdm, 2024-08-08:
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

1. Completed
2.  Completed
3. [printer.cfg](https://gist.github.com/cjhmdm/1047503532acd12d3815e50692e54dfb) & [eddy.cfg](https://gist.github.com/cjhmdm/3b27958191819303f161412e16ab5e51)

4. Unsure what you mean by "run a probe" so including homing results after auto calibration, manual probe calibration results, and bed mesh results. If this is not what you meant, please clarify:

4a. Screenshot after homing (Note: Z-offset is 0.35mm too high from initial calibration at this stage)
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

4b. Screenshots and [printer.cfg](https://gist.github.com/cjhmdm/4888fbdc0ccddcaabafd565cf2f0a1a1) after BED_MESH_CALIBRATE METHOD=scan SCAN_MODE=rapid
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

4c. Screenshot and [printer.cfg](https://gist.github.com/cjhmdm/405248a359e6cd893f93f0b11b013cc5) after PROBE_EDDY_CURRENT_CALIBRATE CHIP=btt_eddy after meshing (this unloads the bed mesh profile, however).
Note: Z-offset is 0.375mm too low at this stage
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

5. Completed

6. Thermal comp [printer.cfg](https://gist.github.com/cjhmdm/81e754e32d0893192abff41e1c844892)

NOTE: Interesting discovery. When homing directly after running the thermal comp the Z position is arbitrarily set to 99.900 as before, but when homing after allowing everything to cool, the Z position appears to be set correctly, which on my machine is ~3.651, which, again, is 0.35mm too low

7a. Homing after thermal comp and adjusting z-offset
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

7b. Screenshot and [printer.cfg](https://gist.github.com/cjhmdm/1e1cd03e72248aa0340c4818d460fb3f) after running PROBE_EDDY_CURRENT_CALIBRATE CHIP=btt_eddy again
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

8. [variables.cfg](https://gist.github.com/cjhmdm/fae6e6781ef8edee69c9d0c0923fb1fa)

bigtreetech, 2024-08-08:
> > > Using the USB...

How high above the bed is the probe when your nozzle is just touching the bed? Also, could you post of a pic of the probe mount?

From your pictures I am seeing strange behaviour when homing. The z-offset with an Eddy based probe does not define the difference between the nozzle and bed when the probe triggers as is the case with normal probes. This is because eddy probes are constantly streaming data telling klipper the current height so there is no defined trigger point. Instead, the z-offset defines that the nozzle should stop during a probing dive. You have set yours to 2mm and therefore the nozzle should stop at 2mm above the bed during a probing dive. Your output says that it is stopping between 1.2 and 1.3mm which is not right. This indicates that there is either something wrong with your mapping calibration (are you pinching the paper correctly?) or your mounting (is there too much metal around the probe? Is it too close or too far from the bed when the nozzle is resting on the bed?).

Pictures of the mount will help to understand this more. Pictures of the probe height with the nozzle touching the bed will also be good.

cjhmdm, 2024-08-08:
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

I have the probe mounted 2mm above the nozzle using your stealthburner files for the EBB SB2209 CAN (RP2040) in combination with the standard Stealthburner files and Rapido HF hotend. The Eddy probe is mounted in the center channel of the SB X-Carriage mount.

cjhmdm, 2024-08-08:
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

cjhmdm, 2024-08-08:
after running through all of the calibrations and letting things cool, then doing some manual z-offset tuning, I'm able to print pretty well... though the images above don't really do the print justice since petg is always messy for me

bigtreetech, 2024-08-08:
I'm running the identical setup to you here on my test rig. My probe is probably mounted a touch higher if anything. I'm able to hit print and forget about it until it is done. I am confident that you can do the same but it will take calibrating properly.

Be sure to zero out the offset value between calibrations as the saved variable may still have old offsets in there. You can use the standard button on the UI to clear the z=offset.

cjhmdm, 2024-08-08:
> I'm running the identical setup to you here on my test rig. My probe is probably mounted a touch higher if anything. I'm able to hit print and forget about it until it is done. I am confident that you can do the same but it will take calibrating properly.
>
> Be sure to zero out the offset value between calibrations as the saved variable may still have old offsets in there. You can use the standard button on the UI to clear the z offset.

I'm mostly fine now, I just need to tinker with the z-offset a bit more (and to be fair, when using the Eddy Coil on my EBB42 and NOT using the beta z-offset, I had the same issues).

The discovery I made today with the temperature comp issue more or less solves that issue (letting everything cool down before trying to use the printer again).

bigtreetech, 2024-08-13:
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

We needed to drop some ports on that board to be able to fit the larger connectors on it. You can use the EBB SB2209 USB that will be released soon as that will allow you to connect the USB eddy to the toolboard as if it were an I2C eddy.

Closing for now as this looks to be resolved.

Closed 2024-08-13.

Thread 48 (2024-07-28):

Issues with Z after BED_MESH_CALIBRATE

cjhmdm, 2024-07-28:
I'm having this issue with both the USB and Coil versions of Eddy.

I'm using Eddy as both the Z endstop as well as the probe

After going through the initial calibration phase, I can correctly get my Z offset/height exactly where I expect, and, after homing, my Z position is about 2.5mm above the bed. When setting Z to 0, the nozzle touches the bed as expected.

Then, after running `BED_MESH_CALIBRATE METHOD=scan SCAN_MODE=rapid` and loading the heightmap, for some unknown reason, it arbitrarily sets my Z position to 5mm even though the actual position is still 2.5mm, so if I were to try to set Z to 0, it would move too low and destroy my print bed (ask me how I know... BTT please send me a new print bed, 377x370mm thx).

No matter what I do, the bed mesh profile incorrectly sets my Z position value to twice its actual position.

NOTE: the 2.5mm and 5mm values vary slightly. In the attached images, the first shows the initial Z position as 2.583mm (correct) and the second shows the z position as 4.973mm (incorrect). The only difference between the 2 images is the loading of the heightmap.
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

bigtreetech, 2024-07-28:
Unable to replicate. Works perfectly when following the exact steps mentioned. Suggest completely erasing your klipper saved config section and performing the calibrations (current, z-mapping and thermal) that are mentioned in the readme guide of this repo. It sounds like there is likely something wrong with your calibration values.

Also ensure that you have followed the guide step by step and are using the appropriate macros from the guide.

If that still fails then feel free to reopen the issue and ensure that you upload your config files and klipper log file from just before you run the bed mesh until just after you scan and home.

Closed 2024-07-28.

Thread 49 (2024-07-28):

Failed calibration - incomplete sensor data

Erop1928, 2024-07-28:
Good afternoon. There was a problem with the calibration of the Eddy Coil sensor.
During calibration, after the command "PROBE_EDDY_CURRENT_CALIBRATE CHIP=btt_eddy" and aligning the nozzle with the piece of paper, the sensor begins to calibrate and then displays the error "Failed calibration - incomplete sensor data"
[klippy.txt](https://github.com/user-attachments/files/16405320/klippy.txt)

Erop1928, 2024-07-29:
Okay, this was solved simply by recalibrating from 50-100 times. Why? Who the hell knows

bigtreetech, 2024-07-29:
This could be due to:

The sensor being a little too close to the bed (raising by 1mm could solve it).
The LDC current calibration data not being correct (if it detected 15 then try to force it to 16).

Erop1928, 2024-08-13:
Unfortunately, both options did not help, the height was from 0.5mm to 4mm (in increments of 0.5 using a probe) relative to the nozzle and changing the LDC current calibration value between 13 and 17 (by unit)
Calibration passes 1 time out of 100. the same with bed mesh calibration, and any interaction with the sensor.
I changed the wires, made a copper screen for them, crimped new wires and connectors
Nothing helped

Today I tried it all day on the new version of klipper (v0.12.0-278-g3f2ef88e). Of course, all MCUs are also updated to this version.
My setup:
BTT CB2 2GB 32GB
Main MCU: Manta M8p 1.0
CAN Adapter: BTT IO2CAN
Toolhead: BTT EBB36 v1.2
MMU: BTT MMB v1.2
And  Eddy Coil

bigtreetech, 2024-08-15:
> Unfortunately, both options did not help, the height was from 0.5mm to 4mm (in increments of 0.5 using a probe) relative to the nozzle and changing the LDC current calibration value between 13 and 17 (by unit) Calibration passes 1 time out of 100. the same with bed mesh calibration, and any interaction with the sensor. I changed the wires, made a copper screen for them, crimped new wires and connectors Nothing helped
>
> Today I tried it all day on the new version of klipper (v0.12.0-278-g3f2ef88e). Of course, all MCUs are also updated to this version. My setup: BTT CB2 2GB 32GB Main MCU: Manta M8p 1.0 CAN Adapter: BTT IO2CAN Toolhead: BTT EBB36 v1.2 MMU: BTT MMB v1.2 And Eddy Coil

Could you take a pic of your mount and post it?

bigtreetech, 2024-08-15:
OK. I feel like you may have a bad Eddy Coil. Please email luke@bigtree-tech.com and I will get you in touch with the support team.

Erop1928, 2024-08-19:
> OK. I feel like you may have a bad Eddy Coil. Please email luke@bigtree-tech.com and I will get you in touch with the support team.

How long does it take to respond?

Erop1928, 2024-08-19:
> OK. I feel like you may have a bad Eddy Coil. Please email luke@bigtree-tech.com and I will get you in touch with the support team.

How long does it take to respond?

bigtreetech, 2024-08-19:
> > OK. I feel like you may have a bad Eddy Coil. Please email [luke@bigtree-tech.com](mailto:luke@bigtree-tech.com) and I will get you in touch with the support team.
>
> How long does it take to respond?

No email has arrived. Please check that you used the correct address.

Erop1928, 2024-08-20:
> No email has arrived. Please check that you used the correct address.
Seems to be correct (Wrote again)
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
Maybe you can write to me at erop1928@gmail.com?

Erop1928, 2024-09-02:
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
For some reason, when it comes to Luke, you stop responding. Apparently your "write a letter to Luke about this problem" means "go to hell with your problems"

bigtreetech, 2024-09-03:
> ![browser_24yDBi5r7H](https://private-user-images.githubusercontent.com/33271224/363787729-5ba80880-aed3-4f1b-898e-a0cf765dffbf.png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) For some reason, when it comes to Luke, you stop responding. Apparently your "write a letter to Luke about this problem" means "go to hell with your problems"

I am the CTO of a company and have more to do every single day than almost every other person I meet. Your message has arrived and will be tended to as soon as it reaches the top of the queue.

Erop1928, 2024-09-03:
Ok, thanks for the answer, asking for expectation is always better than uncertainty.
If there is a possibility that this is a marriage, it is much easier for me to buy a new sensor.

Closed 2024-07-29.

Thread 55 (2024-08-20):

Nozzle crash after performing Z_TILT_ADJUST with the Eddy coil

cssi-dev, 2024-08-20:
I tried printing the first part after switching to the new probe. I was suprised to learn, that my print was canceled during the print start macro.
Error:

> probe triggered prior to movement

with `horizontal_move_z: 5 `

So I switched it to `horizontal_move_z: 10`(even though In the bed section the horizontal_move_z is just 2 ), to then get the nozzle crash because the printer after getting all the readings moved all z axes way to far.

I get that you are not supposed to use the eddy coil for homing because of the temprature drift. But please let us use the Tilt adjust. I don't want to switch every 5-10 prints between the probes just to readjust the z axis when it gets out of wack.

Steps to reproduce:

Home the Printer
Start `Z_TILT_ADJUST`
Be ready to shutdown the printer befor something bad happens
[klippy.log](https://github.com/user-attachments/files/16667168/klippy.log)

Edit: added relevant config
[config-20240821-015955.zip](https://github.com/user-attachments/files/16683644/config-20240821-015955.zip)

Edit 2: I found out why it crashed! The probe stays in the open position. no matter if it touches the bed or is far away.
Steps to reproduce:
move probe far away from the bed
QUERY_PROBE
move the bed close to the sensor / hold a heavy metal part in front of the sensor
QUERY_PROBE

cssi-dev, 2024-08-23:
Since it seams that I won't get an answer any time soon, can you at least point me to the correct file so I can at least try to creat a fork with a fix. Thanks already

BTTJUSTIN, 2024-09-06:
Thanks for reporting. We will get our engineering team to look into this.

cssi-dev, 2024-09-07:
Thank you for your response. The klipper support and I already found a solution.(The initial z offset was way to low). I would advice to change the guide so that it is no longer inside the Probe itself and that it has to be calibrated with the Probe query command (which is still missing).
By the way is temprature compensation apperently always requiert since ztilt only works when you do the calibration(even  if you would not need it)

bigtreetech, 2024-09-09:
> Thank you for your response. The klipper support and I already found a solution.(The initial z offset was way to low). I would advice to change the guide so that it is no longer inside the Probe itself and that it has to be calibrated with the Probe query command (which is still missing). By the way is temprature compensation apperently always requiert since ztilt only works when you do the calibration(even if you would not need it)

That is not how Z-offset works with these probes. See the FAQ section of the readme in this repo for a link to an explanation of how z-offset works with these probes. It is very different to standard z-offset and the query_probe command has no meaning.

Closed 2024-09-09.

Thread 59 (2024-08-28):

Probe triggered prior to movement after moving to klipper main release

madk71, 2024-08-28:
Hi, I was able to have the eddy working with very few issues using your klipper fork, so I thought that moving to the master release probably I can have some fixes. I modified the repository in kiauh, updated all, and reflashed the eddy and I was unable to run the PROBE_EDDY_CURRENT_CALIBRATE_AUTO, as soon I press any of the buttons to adjust the z I receive the error that axes need to be homed (x and y were homed) and of course, the z can't be homed if I don't run the current calibration. I copied the old value of the PROBE_EDDY_CURRENT_CALIBRATE_AUTO, restarted klipper, and ran PROBE_EDDY_CURRENT_CALIBRATE_AUTO and this time it was working. So I calibrated eddy and saved it. At this point, I did the bed mesh and then tried to level the bed with SCREWS_TILT_CALCULATE after homing of course, but I received the Probe triggered prior to movement error. The same is true for the Z_TILT_ADJUST.
I created a new sd card with a fresh install of everything and reflashed the eddy again, but I received all the same errors and problems.
attached you can find my cfg files and log.

[klippy.log](https://github.com/user-attachments/files/16788858/klippy.log)
[config-files.zip](https://github.com/user-attachments/files/16788897/config-files.zip)

bigtreetech, 2024-08-29:
Please adjust your macro to match the one here and let me know if it helps:

[gcode_macro SET_Z_FROM_PROBE]
gcode:
    {% set cf = printer.configfile.settings %}
    SET_GCODE_OFFSET_ORIG Z={printer.probe.last_z_result - cf['probe_eddy_current btt_eddy'].z_offset + printer["gcode_macro SET_GCODE_OFFSET"].runtime_offset}
    G90
    G1 Z{cf.safe_z_home.z_hop}

madk71, 2024-08-29:
Hi, Thanks. the new code fixed the problem

Closed 2024-08-30.

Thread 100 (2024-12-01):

Error on 'PROBE_EDDY_CURRENT_CALIBRATE': missing CHIP

thereealnio, 2024-12-01:
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

I have a Voron 2.4r2, with a raspberry pi4 and a btt octopus mainboard and 2x Sovol SV08 printers. Till now, i was using tap on the Voron, and it was working as expected.
I decided to replace the sensor of one of the SV08 with an eddy usb, and the process was smooth.
I have then, decided to replace the tap on the Voron, and i am getting the following error: Error on 'PROBE_EDDY_CURRENT_CALIBRATE': missing CHIP

I can successfully perform the LDC_CALIBRATE_DRIVE_CURRENT CHIP=btt_eddy .
I get the response: probe_eddy_current btt_eddy: reg_drive_current: 15
The SAVE_CONFIG command will update the printer config file
with the above and restart the printer.

and then i SAVE_CONFIG.

Once the printer restarts, i am sending the PROBE_EDDY_CURRENT_CALIBRATE_AUTO command, the device performs a homing on the X and Y axis, and right after that, it produces the" Error on 'PROBE_EDDY_CURRENT_CALIBRATE': missing CHIP", twice.

Steps i have performed so far:

Tried with a new eddy usb (i had ordered 3), with a different usb cable, and i got the same error message.
Updated everything to the latest version.
I have removed and re-installed, through KIAUH,  Klipper, Moonraker, Mainsail, and Crowsnest.
I have tried different usb ports on the rpi, a different psu (the original from raspberry).
I have tried to re-configure the whole setup from scratch, by re-downloading the latest printer.cfg from BigTreeTech
And, i have tried googling about it, so, rest assured, i will not be getting a response like: "let me google this for you".

At this point, i really can not understand what i am doing wrong, and why i am getting this error... (upgrading everything is not an option, it's no longer "blackfriday" ;-)

Thank you all in advance for your replies

MasterSe7en777, 2024-12-02:
im having the same issue, but the weird thing is, i did get it working once, and then it stopped.... and its back to doing it again...so i have no clue im still trying to figure it out

Rotifox, 2024-12-02:
I'm joining in. I have the same error. I have the USB eddy that seems to be giving a lot of problems.

Darth-Kuni, 2024-12-07:
i get this same error has any one fixed it yet ?

thereealnio, 2024-12-07:
Well... I did...!
After MasterSe7en777 commented and said that it worked once, and since I knew it was not a faulty hardware, I did 2 things.
1, I replaced the "simple" template, with the "full" one. (Z probe plus experimental settings)
2, (it might sound stupid.... I made sure, when entering the PROBE_EDDY_CURRENT_CALIBRATE_AUTO
CHIP=btt_eddy
Command, that the second line, is actually in line, and there is no line change there... Like this: PROBE_EDDY_CURRENT_CALIBRATE_AUTO CHIP=btt_eddy

The 2 lines seem identical in the console, but the one on the top is with enter, and the one on the bottom has a simple space.

Since then, it has been working fine for me. I think, we all fell victimes of a bad guide and our copy - paste skills....

IF you also get it working the way I did, please reply, so that people will know!

MasterSe7en777, 2024-12-07:
So I figured out the problem with mine, if you are using canbus you have to remember to remove the 120ohm resistor jumper from your toolboard in my case it was from my sb2209 because the Eddy has a built in 120ohm resistor so it is one end of the can bus and my manta e3ez also has a jumper, you can't have 3 120ohm resistors on the bus...

I don't know what you guys are using but if you have a setup that's the same as mine you need to make sure you remove one of the jumpers and you have to remove the one in the middle of the network which is on the sb2209

thereealnio, 2024-12-07:
I had it on Eddy USB, not the can version

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

Darth-Kuni, 2024-12-07:
thereealnio thank you so much that worked

so the PROBE_EDDY_CURRENT_CALIBRATE_AUTO CHIP=btt_eddy has to be on 1 line
so simple
eddy duo canbus
m5p

MasterSe7en777, 2024-12-08:
Ok so removing the 120ohm jumper combined with threealnios fix, it's all working perfectly thank you all

Closed 2025-01-25.

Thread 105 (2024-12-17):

Eddy USB calibration issues

Drastil11, 2024-12-17:
I have an Eddy USB, using the latst version of klipper and the eddy probe is flashed with firmware from the latest version of klipper.
Cople of issues that come up.

1.  When I first set the z height and the probe moves to the position to calibrate the sensor, I get a loud screeching noise coming from the extruder stepper and I get a move exceeds maximum extrusion error. I then have to put 200 or so in the maximum extrusion section for the extruder. I no longer get the error but the extruder stepper still makes a god awful sound.
2.  When calibrating the thermal drift compensation, the movement of the probe from the z-height measurement (paper test) position to the probe calibration position is way too slow. By the time the probe itself reaches the position of calibrate for temperature, the temperature has increase 2 or 3 degrees and then, when it moves back for the next temperature interval, it moves so slow that the temperature has climbed beyond the 3 or 4 degree threshold to trigger and z-height measurement. Any way to speed up the movement between paper test and probe calibration?
3.  The following macro (direct from BTT's instructions) always gives me the error "missing chip". I am assuming it has to do with the rawparams portion of the macro. Can I just change that raparams to CHIP=btt_eddy and go from there?
[gcode_macro PROBE_EDDY_CURRENT_CALIBRATE_AUTO]
gcode:
  BED_MESH_CLEAR
  G28 X Y
  G90 # Abs positioning
  G1 X{ printer.toolhead.axis_maximum.x/2 } Y{ printer.toolhead.axis_maximum.y/2 } F6000
  {% if 'z' not in printer.toolhead.homed_axes %}
    SET_KINEMATIC_POSITION Z={ printer.toolhead.axis_maximum.z-1 } # Allows the user to work it down until it touches.
  {% endif %}
  PROBE_EDDY_CURRENT_CALIBRATE {rawparams}

Any help would be greatly appreciated.

dugly66, 2024-12-20:
I got it to work by changing the last line of that macro to this
 PROBE_EDDY_CURRENT_CALIBRATE CHIP=btt_eddy #{rawparams}

Drastil11, 2024-12-21:
Thanks for the reply. Got it working with your suggestion.
I fixed the other two on my own

Closed 2025-01-25.

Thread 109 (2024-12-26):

Rethink how homing is handled

vvuk, 2024-12-26:
I was trying to understand some weirdness with the btt eddy probe. Mainline klipper (from last week), sovol sv08, valerie moore's mount (lower position; the remix'd Eddy Duo mount). BTT Eddy config _without_ the "beta Z offset". I've kept temps consistent at the temp that the eddy was calibrated at; no temp curve in play.

Note that the way homing is handled here is I think broken. Homing is about mapping the printer's stepper position to an actual physical distance. Using the GCODE z_offset to do this is wrong, and then requires gross hacks like the "beta z offset" stuff.

The probe's `z_offset` is set to 2.5, i.e. the probe's trigger point is at 2.5mm off the bed. What I expect to happen: `G28` to home the axes. Then `PROBE_ACCURACY` should report 2.50xxx (i.e. -- when the steppers are at what they think is physical 2.5mm based on the homing, the probe should report 2.5mm).

Instead, what happens is I consistently get numbers from accuracy that are around 2.50-2.65mm, with wide variance. If I use BTT's macros, I can see their macros setting the gcode z offset to things like 0.21, 0.15, 0.05, 0.25, etc.; wildly different value with every Z home. (Can see this by just doing `G28 Z` multiple times.)

`PROBE_ACCURACY` gives very repeatable results (typically stddev 0.001). My theory as to what's happening is that the homing code with the virtual z endstop has some variable latency between the endstop trigger actually happening and it interrupting the homing z axis downward movement.

I've added [reporting the probe accuracy results as status to probe.py](https://github.com/vvuk/klipper/commit/bd34316d5d29d47822150636134ce574f33fbf1b) and I've [changed the homing macro to use it like this](https://github.com/vvuk/sv08-config/blob/a04287c3232931ea1a35c7e26197185ddd60c46c/eddy.cfg#L73), and I'm getting far better and more accurate results.

bigtreetech, 2024-12-27:
The klipper homing dive only looks for a single trigger and then stops. This is not suitable for an eddy probe that requires an average over several samples. The way that the home therefore works is that it performs a standard home with the knowledge that there will be some error because klipper is only relying on a single sample to trigger. Thereafter it performs a probe sequence in exactly the same xy location which behaves quite differently in that it averages the trigger point over several samples. The probe will be more accurate but it is still looking for a height of 2.5mm to trigger at. Since we know that the homing dive *should* have triggered at 2.5 we can calculate the inaccuracy by subtracting the probe dive from the homing dive results. I.e. if the probe dive triggers at 2.6mm then we know that we were actually 0.1mm high during the home and we need to subtract 0.1mm from the homed z position which is implemented in the SET_Z_FROM_PROBE macro.

Until the entire homing part of klipper can be reworked, this is an effective and transparent solution. Your macro works in a similar manner but it simply performs more probing dives which is not required since the standard probe is already sampling so fast that a single dive already gathers tens of samples and averages them. The only other difference is that your macro is using the SET_KINEMATIC_POSITION gcode which is not recommended relative to the option to simply perform an axis transform as is already being done in the original code.

Z-offsets are a completely different discussion. For more info on how z offsets work and why a standard z-offset no longer applies with an eddy probe see this write up. We are working to update the mainline klipper codebase so that it is better suited to these types of probes without the need for macros.

https://gist.github.com/bigtreetech/484380b26be613b9139bc537510393df

vvuk, 2024-12-27:
> a single dive already gathers tens of samples and averages them

Is this true? The ldc1612 driver uses a single trigger point frequency and does no averaging of the frequency values. [This patch does, though.](https://github.com/KevinOConnor/klipper-dev/commit/beb02f77c8f893da6b2590622294d7bceb758926). The default for probe samples is 1, and ultimately this [goes down into `probing_move` here](https://github.com/Klipper3d/klipper/blob/80d185c94c8dbec7f19d791995242af1bb197057/klippy/extras/probe_eddy_current.py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) which does do an average of the frequencies (in `note_probe` -> `_check_samples` -> `_pull_freq`), but it's still only during one dive. Let me know if I'm wrong, though! This code all seems overly complex for what should ultimately be a simple operation, so I'm missing something :)

Also, I don't understand the `+ 0.05` / `+ 0.10` in the start_time/end_time there -- I believe the time units are in seconds? And `trigger_time` is the time the probe actually triggered... why is the code taking the average of the range 50ms-100ms _after_ that to map to the physical toolhead position?

You're right about `PROBE_ACCURACY` though -- I was getting better results with an average, but the right way to do that would be to just increase `samples` under the eddy probe config, no reason to go through the accuracy dance.

> The only other difference is that your macro is using the SET_KINEMATIC_POSITION gcode which is not recommended

Why not recommended? Homing is explicitly the act of setting an accurate kinematic position, so this seems appropriate. It also presents a much better experience to the user -- the z offset value is meaningless if it's set as part of homing, as the user can't think of it as "this is the offset to apply relative to what my hardware thinks is z=0". Instead if they do apply an offset they also need to remember "ok, 0.210 is actually zero" if they want to make adjustments.

And unfortunately the concept of needing to add a z offset still applies; bad thermal calibration/thermal expansion, user preference etc, can all cause someone to want to adjust the z offset on the fly. Sure, the concept of `[probe] z_offset` doesn't apply (it should really be named `probe_trigger_z` or something), but

vvuk, 2025-01-13:
@bigtreetech just FYI -- I've mostly rewritten the eddy current sensor code & some of the LDC code in order to clean up the code and implement "tap" functionality for precise z-offset. There's a [readme document here](https://github.com/vvuk/klipper/blob/vlad/eddy-ng/README_eddy_ng.md) and that branch has the code. I'm in the process of gathering more testers and data, though it's working well for me with a BTT Eddy Duo (but the coil design I think is somewhat limiting). Feel free to reach out if you're interested in discussing more, either on discord (@vladv) or email (vladimir at pobox dot com).

Closed 2024-12-27.

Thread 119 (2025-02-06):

intermittent "Error during homing z: Communication timeout during homing"

Joshua1859, 2025-02-06:
When homing I'm getting (sometimes) this error but i simply home the printer or restart the print and seems to work, what's the problem? I don't understand.

bigtreetech, 2025-02-06:
Likely not related to the probe. This seems like a comms issue with your setup. Lots of info here. https://klipper.discourse.group/t/canbus-communication-timeout-while-homing-z/3741/60

Joshua1859, 2025-02-06:
I'm using usb with eddy duo.

bigtreetech, 2025-02-06:
Have you checked your logs to look for lost packets? Not only that but your SBC may be overloaded and causing packets to wait in the return queue for too long. What SBC are you using?

Joshua1859, 2025-02-06:
I'm using a PI 2. I can't seem to find anything in the log but im not quite sure what to look for.

Joshua1859, 2025-02-06:
And what i find strange is that most of the time on the second maybe third time at the worst it seems to work. I think the further away from the bed the more times I have to do the homing again.

bigtreetech, 2025-02-06:
Yea, that is something that I have personally had in the past too. It can be very difficult to track down but it is generally related to messages waiting in the incoming queue for too long.

Is it a BTT Pi2? If so then we have a new image that is currently in beta. We will be making releases rapidly over the next two weeks until we get to the final version. The linux kernel is far more efficient and maybe it will help with this issue.

Joshua1859, 2025-02-06:
No a Raspberry Pi 2.

bigtreetech, 2025-02-06:
> No a Raspberry Pi 2.

Oh OK. In that case the issue is almost certainly your pi. It is just too slow to handle the incoming messages.

Joshua1859, 2025-02-06:
Oh ok I'll have to use a phyical endstop instead.

bigtreetech, 2025-02-06:
One thing that you may want to try is to use the lite version of raspbian. If you are using the desktop version then there will be a lot of resources that are eaten needlessly.

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

motogon, 2025-04-05:
I have the same problem , I regularly get an error in klipper "!!!! Error during homing z: Communication timeout during homing" - and because of this , I can not use the printer with your device . Connection via usb .

I have klipper running on Host (x86_64, 64bit)
Version: v0.12.0-458-gd886c1761
OS: Debian GNU/Linux 12 (bookworm)
(virtual machine)

Tried it on a single hardware computer where klipper is the only software.

In both cases - the problem with your device is repeated.
In several attempts - 1 out of 10, it works properly, in other cases - an error.

Closed 2025-02-06.

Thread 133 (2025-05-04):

Eddy Duo CAN - Install Questions

wsturner88, 2025-05-04:
Hoping for some help in getting the Eddy Duo Can connected to the CAN on the SB2209 Daughter Board.

1) Flashed Katapult to the Eddy Can (Switch in USB Mode)
2) Installed the Eddy Duo to the Daughter Board of the SB2209 (Switch on Duo is now CAN)

DO I REMOVE THE 120R resistor from the SB2209???

Via terminal:
python3 ~/katapult/scripts/flashtool.py -i can0 -q

I get no Nodes..

Any recommendations?

bigtreetech, 2025-05-04:
What comms did you configure katapult for in the make menuconfig?

wsturner88, 2025-05-04:
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

bigtreetech, 2025-05-04:
> 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

The status LED should be blinking once per second if it has entered into katapult. You also need to ensure that the baud rate in the can 0 config file on your SBC is set to the same baud rate as the Eddy (1Mbps). If the status LED is not blinking then katapult may think that there is a valid application in the memory and be jumping into it. You would need to erase the whole memory of the RP2040 to prevent that and I would recommend using the USB interface for that purpose.

wsturner88, 2025-05-04:
Thank you for the quick reply..
Light on Eddy Duo CAN is solid

When I flash Katapult, do I have the switch on CAN or USB?   I originally flashed Katapult via the USB on the Rpi (Switch USB) then changed to CAN and installed onto the CAN bus.  Correct?

How to you ensure you erase the memory on the RP2040?

bigtreetech, 2025-05-04:
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

Flashing anything onto the Eddy should be done via USB unless you are using katapult and have successfully managed to get it to work previously. Until then, all should be via USB.

Process would be to flash via USB but configure the katapult bootloader to communicate via CAN in the future (as you have done). Also set the CLKDIV to 4 instead of 2. There was a recent change in klipper that broke compatibility with some flash chips and now this extra setting is required. We will be updating our documentation accordingly.

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

To erase the chip memory follow the instructions here: https://www.raspberrypi.com/documentation/microcontrollers/pico-series.html#resetting-flash-memory

wsturner88, 2025-05-04:
THANK YOU!   The CLKDIV was the issue.. Below is the Katapult config that worked

ANOTHER NOTE - ON YOUR SB2209 LEAVE R120 Jumper on.

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

Closed 2025-05-04.

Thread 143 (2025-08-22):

Tap mount useless?

jangrewe, 2025-08-22:
I just rebuilt my toolhead to use a ChaoticLab Tap V2 and also bought an Eddy Duo as i saw that there is an "official" mount in this repo: https://github.com/bigtreetech/Eddy/tree/master/3D/EDDY_PRINT_PARTS/Eddy_TapV2

So i printed that, bolted it onto the Tap V2, installed the Tap V2 to my X axis, and then noticed that the Tap V2 is now not a Tap anymore, but just as toolhead bracket, as it doesn't move up anymore - and that's even without the cables installed!

So i'm wondering what the point of the mount for the Tap V2 is, if it doesn't tap anymore after adding Eddy to it?

jangrewe, 2025-08-22:
How is the firmware for the probe related to the mount you're providing, and that it physically(!) stops the toolhead from being able to move up and down on the Tap rail?

One is software, the other is hardware....

bigtreetech, 2025-08-22:
Personally, I can't speak for your issues with the mount as I have never used it in an individual capacity. Github is here primarily to monitor firmware issues which is what I am more familiar with (not that I don't want to help more but I am just explaining the process).

Eddy-ng is firmware that turns the eddy into a tap probe with incredible accuracy. It completely negates the need for the CNC Tap V2. Nevertheless, I am 100% confident that the mount has been tested as I recall a trusted colleague designing and testing it. If you don't like the idea of eddy-ng then I would recommend contacting the official support channel using the ticketing system on our website where someone will be better geared to assist. Alternately, you could also consider this as you may just be using a hotend that is incompatible with the BTT mount (also completely untested by me in an individual capacity): https://www.printables.com/model/1011227-btt-eddy-mount-for-chaoticlab-tap-v2

Closed 2025-08-22.

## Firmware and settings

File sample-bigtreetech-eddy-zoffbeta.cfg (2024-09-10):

# The MCU section only applies to the Eddy USB. For Eddy Coil you will use the MCU name of the toolboard that you connected the Eddy Coil to.
[mcu eddy]
serial: /dev/serial/by-id/usb-Klipper_rp2040_eddy-if00 # This is the serial address of your eddy probe. This can be found by using the terminal of your klipper instance (typically through SSH) and using the command ```ls /dev/serial/by-id``` 
restart_method: command
Did you read all of the comments before the macros? Make sure that you do and then uncomment the ones that you need. Remove this line when you are done.

[temperature_sensor btt_eddy_mcu]
sensor_type: temperature_mcu # Sets the type of sensor for Klipper to read
sensor_mcu: eddy # Sets the MCU of the eddy probe tempereature sensor
min_temp: 10 # Sets the minimum tempereature for eddys tempereature sensor to operate
max_temp: 100 # Sets the maximum tempereature for eddys tempereature sensor to operate

[probe_eddy_current btt_eddy]
sensor_type: ldc1612
z_offset: 2.5
#i2c_address:
i2c_mcu: eddy  # This value is good for the Eddy USB but would need to be adjusted for the Eddy Coil according to the MCU you have used.
i2c_bus: i2c0f # This value is good for the Eddy USB but would need to be adjusted for the Eddy Coil according to the I2C bus you have used.
# Measure the offsets below using the method described here: https://www.klipper3d.org/Probe_Calibrate.html#calibrating-probe-x-and-y-offsets
# For a standard Voron stealthburner X carriage mount there should be no need to change the defaults below.
x_offset: 0
y_offset: 21.42

# This section is only relevant for Eddy USB. Comment it out for Eddy Coil.
[temperature_probe btt_eddy]
sensor_type: Generic 3950
sensor_pin: eddy:gpio26
horizontal_move_z: 2

[bed_mesh]
horizontal_move_z: 2
speed: 200
# For the mesh dimensions below, the coordinates need to be reachable by the center of the probe. To calculate coordinates that will work, use the formula below:
# mesh x min = position_min_x + greater_of (15mm or x_offset) <--- in this term, only consider the x offset if it is positive, ignore if negative.
# mesh y min = position_min_y + greater_of (15mm or y_offset) <--- in this term, only consider the y offset if it is positive, ignore if negative.
# mesh x max = position_max_x - greater_of (15mm or |x_offset|) <--- in this term, only consider the x offset if it is negative, ignore if positive.
# mesh y max = position_max_y - greater_of (15mm or |y_offset|) <--- in this term, only consider the y offset if it is negative, ignore if positive.
# Example: Consider that you have a 300 x 300 bed with the max x and y positions being 300 and the min being 0. Your probe offsets are -20 for X and 10 for Y
# For mesh x min we ignore the x offset term because it is negative. Therefore mesh x min = 15
# For mesh y min we do not ignore the y offset term because it is positive but it is less than 15 so we use 15. Therefore mesh y min = 15
# For mesh x max we do not ignore the x offset term because it is negative. It is also greater than 15. Therefore mesh x max = 280
# For mesh y max we ignore the y offset term because it is positive but it is less than 15 so we use 15. Therefore mesh y max = 285
# The final result would be mesh_min: 15, 15 mesh_max: 280, 285
mesh_min: 10, 10  # modify these according to the above guide. If the probe cannot reach then you will get a klipper error when trying to scan a bed mesh.
mesh_max: 220, 220 # modify these according to the above guide. If the probe cannot reach then you will get a klipper error when trying to scan a bed mesh.
probe_count: 9, 9
algorithm: bicubic
#scan_overshoot: 8  #uncomment this section if you still have room left over on the X axis for some scan overshoot to product smoother movements and more accurate scanning. Uncommenting this should be fine if you are using a standard voron mount.

# Uncomment this if you are using Eddy as the probe AND the homing endstop
[safe_z_home]
home_xy_position: 150, 150 # Choose an X,Y position that is in the center of your bed. For a 300x300 machine that will be 150, 150. Use the same principle to calculate your bed center.
z_hop: 10
z_hop_speed: 25
speed: 200

###############################Macros and related################################
#This secton contains macros and related config sections. Some should be used, others are optional. Read the comment above each one to find out whether or not to uncomment it for your installation.


# Uncomment this if you are using Eddy as the probe AND the homing endstop AND would like to use the beta z-offset control
[save_variables]
filename: ~/printer_data/config/variables.cfg



# Uncomment this if you are using Eddy as the probe AND the homing endstop
[force_move]
enable_force_move: True # Allows a user to move the z axis down if they have no other means of homing Z and need to calibrate the Eddy.



# Uncomment this if you are using Eddy as the probe AND the homing endstop AND would like to use the beta z-offset control
[delayed_gcode RESTORE_PROBE_OFFSET]
initial_duration: 1.
gcode:
  {% set svv = printer.save_variables.variables %}
  {% if not printer["gcode_macro SET_GCODE_OFFSET"].restored %}
    SET_GCODE_VARIABLE MACRO=SET_GCODE_OFFSET VARIABLE=runtime_offset VALUE={ svv.nvm_offset|default(0) }
    SET_GCODE_VARIABLE MACRO=SET_GCODE_OFFSET VARIABLE=restored VALUE=True
  {% endif %}



# Uncomment this if you are using Eddy as the probe AND the homing endstop
# Take note of the lines that should only be used if you have a KNOMI installed.
[gcode_macro G28]
rename_existing: G28.1
gcode:
  #SET_GCODE_VARIABLE MACRO=_KNOMI_STATUS VARIABLE=homing VALUE=True # Uncomment this if using a KNOMI and then remove the G28 macro from the KNOMI.cfg
  G28.1 {rawparams}
  {% if not rawparams or (rawparams and 'Z' in rawparams) %}
    PROBE
    SET_Z_FROM_PROBE
  {% endif %}
  #SET_GCODE_VARIABLE MACRO=_KNOMI_STATUS VARIABLE=homing VALUE=False # Uncomment this if using a KNOMI and then remove the G28 macro from the KNOMI.cfg



# Uncomment this if you are using Eddy as the probe AND the homing endstop
[gcode_macro SET_Z_FROM_PROBE]
gcode:
    {% set cf = printer.configfile.settings %}
    SET_GCODE_OFFSET_ORIG Z={printer.probe.last_z_result - cf['probe_eddy_current btt_eddy'].z_offset + printer["gcode_macro SET_GCODE_OFFSET"].runtime_offset}
    G90
    G1 Z{cf.safe_z_home.z_hop}


# Uncomment this if you are using Eddy as the probe AND the homing endstop AND would like to use the beta z-offset control
[gcode_macro Z_OFFSET_APPLY_PROBE]
rename_existing: Z_OFFSET_APPLY_PROBE_ORIG
gcode:
  SAVE_VARIABLE VARIABLE=nvm_offset VALUE={ printer["gcode_macro SET_GCODE_OFFSET"].runtime_offset }



# Uncomment the lines in this macro if you are using Eddy as the probe AND the homing endstop AND would like to use the beta z-offset control
[gcode_macro SET_GCODE_OFFSET]
rename_existing: SET_GCODE_OFFSET_ORIG
variable_restored: False  # Mark whether the var has been restored from NVM
variable_runtime_offset: 0
gcode:
  {% if params.Z_ADJUST %}
    SET_GCODE_VARIABLE MACRO=SET_GCODE_OFFSET VARIABLE=runtime_offset VALUE={ printer["gcode_macro SET_GCODE_OFFSET"].runtime_offset + params.Z_ADJUST|float }
  {% endif %}
  {% if params.Z %} 
    {% set paramList = rawparams.split() %}
    {% for i in range(paramList|length) %}
      {% if paramList[i]=="Z=0" %}
        {% set temp=paramList.pop(i) %}
        {% set temp="Z_ADJUST=" + (-printer["gcode_macro SET_GCODE_OFFSET"].runtime_offset)|string %}
        {% if paramList.append(temp) %}{% endif %}
      {% endif %}
    {% endfor %}
    {% set rawparams=paramList|join(' ') %}
    SET_GCODE_VARIABLE MACRO=SET_GCODE_OFFSET VARIABLE=runtime_offset VALUE=0
  {% endif %}
  SET_GCODE_OFFSET_ORIG { rawparams }



# This macro automates a lot of the frequency mapping process and simplifies the steps significantly.
[gcode_macro PROBE_EDDY_CURRENT_CALIBRATE_AUTO]
gcode:
  BED_MESH_CLEAR
  G28 X Y
  G90 # Abs positioning
  G1 X{ printer.toolhead.axis_maximum.x/2 } Y{ printer.toolhead.axis_maximum.y/2 } F6000
  {% if 'z' not in printer.toolhead.homed_axes %}
    SET_KINEMATIC_POSITION Z={ printer.toolhead.axis_maximum.z-1 } # Allows the user to work it down until it touches.
  {% endif %}
  PROBE_EDDY_CURRENT_CALIBRATE {rawparams}



#This macro is optional but useful if you want to run a rapid scan before each print. Simply uncomment it and add BED_MESH_SCAN to your print start code.
#[gcode_macro BED_MESH_CALIBRATE]
#rename_existing: BTT_BED_MESH_CALIBRATE
#gcode:
#  SET_GCODE_VARIABLE MACRO=_KNOMI_STATUS VARIABLE=probing VALUE=True #Only uncomment this line if using a KNOMI and then remove the BED_MESH_CALIBRATE macro from KNOMI.cfg
#  BTT_BED_MESH_CALIBRATE METHOD=rapid_scan
#  SET_GCODE_VARIABLE MACRO=_KNOMI_STATUS VARIABLE=probing VALUE=False #Only uncomment this line if using a KNOMI and then remove the BED_MESH_CALIBRATE macro from KNOMI.cfg

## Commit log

2024-04-23 fix eddy tap v2 .step file
    [TAP V2-UHF-EDDY.STEP]
2024-04-28 update tap v2 .step
    [TAP V2-Eddy-0424.STEP, TAP V2-UHF-EDDY.STEP]
2024-05-20 Added Ender 3 Max adjustable mount and Eddy calibration block (#11)
    * Added Ender 3 Max adjustable mount and Eddy calibration block - DaveTheBuskerUK 20240517
    * Community_Mods
    ---------
    [E3Max-BIQU_Eddy_Probe_Mount-Block-V0-1.stl, E3Max-BIQU_Eddy_Probe_Mount-Slide-V0-1.stl, E3Max-BIQU_Eddy_Probe_Mount-Spacer-V0-1.stl]
2024-05-24 Update sample-bigtreetech-eddy.cfg (#13)
    Adds some explanation to the different lines to add ease of use for changing values.
    This is open to changes, and altering of definitions.
    [sample-bigtreetech-eddy.cfg]
2024-05-25 Updated Guide and Cleaned up
    Added
    - dimensions
    - probe location
    - changed to host device
    - added offset fix
2024-05-29 Added klipper firmware information
    Users should have up-to-date klipper firmware. Added a reminder before continuing with guide.
2024-06-06 Small typo in README.md
    Changed "currant" to "current" in section 2 step 18
2024-06-06 Spelling fix
    changed currant to current
2024-06-12 Create H2V2S extruder
2024-07-02 Updated cfg to be more verbose and contain useful macros
    [sample-bigtreetech-eddy.cfg]
2024-07-03 Updates to the sample config file
    [sample-bigtreetech-eddy.cfg]
2024-07-03 more tweaks to sample config
    [sample-bigtreetech-eddy.cfg]
2024-07-03 Updated the offset to the exact value
    [sample-bigtreetech-eddy.cfg]
2024-07-03 Made the mapping easier via a macro and more updates to the guide
    [sample-bigtreetech-eddy.cfg]
2024-07-08 Updated the sample config to indicate which sections should be uncommented based on user needs.
    [sample-bigtreetech-eddy.cfg]
2024-07-09 Split config files and update guide accordingly.
    [sample-bigtreetech-eddy-homing.cfg, sample-bigtreetech-eddy-zoffbeta.cfg]
2024-07-09 Readme tweaks and final touches to config files
    [sample-bigtreetech-eddy-homing.cfg, sample-bigtreetech-eddy-zoffbeta.cfg, sample-bigtreetech-eddy.cfg]
2024-08-12 Updates to the guide for mainline klipper compatibility
    [sample-bigtreetech-eddy-homing.cfg, sample-bigtreetech-eddy-zoffbeta.cfg, sample-bigtreetech-eddy.cfg]
2024-08-12 more tweaks to gcodes that were updated in mainline klipper
2024-08-13 Updated toolboard klipper compile instructions to master branch
2024-08-29 Update bed mesh calibrate command
2024-08-29 Minor updates to macros to resolve some issues
    [sample-bigtreetech-eddy-homing.cfg, sample-bigtreetech-eddy-zoffbeta.cfg, sample-bigtreetech-eddy.cfg]
2024-09-10 Updated z-offset in config files so that the trigger point is a little higher in line with various customer feedback reports of having more reliable operation at a higher trigger point.
    [sample-bigtreetech-eddy-homing.cfg, sample-bigtreetech-eddy-zoffbeta.cfg, sample-bigtreetech-eddy.cfg]
2024-12-11 update manual: wiring to octopus
